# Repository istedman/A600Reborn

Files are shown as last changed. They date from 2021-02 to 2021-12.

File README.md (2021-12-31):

# A600Reborn

Amiga A600 schematics recaptured in KiCad and a new PCB design created from them. 
There is currently one, working, version which replaces the RF modulator with a mini-DIN for S-video.

Schematics and baseline PCB captured by Mick @ EAB. Checked and updated by myself.

Original thread is here: http://eab.abime.net/showthread.php?t=98176

<B>Status as of 23rd February 2021</B><P>
  
The Baseline version is still undergoing testing and is currently not fully functioning, this vairant is not published here.
Use the A600_S_Video branch if you want to try the working variant.

The S-Video variant, which was tracked via manual methods, rather than auto-routed, currently works and boots.
<B> Photos of the S-Video variant<B>

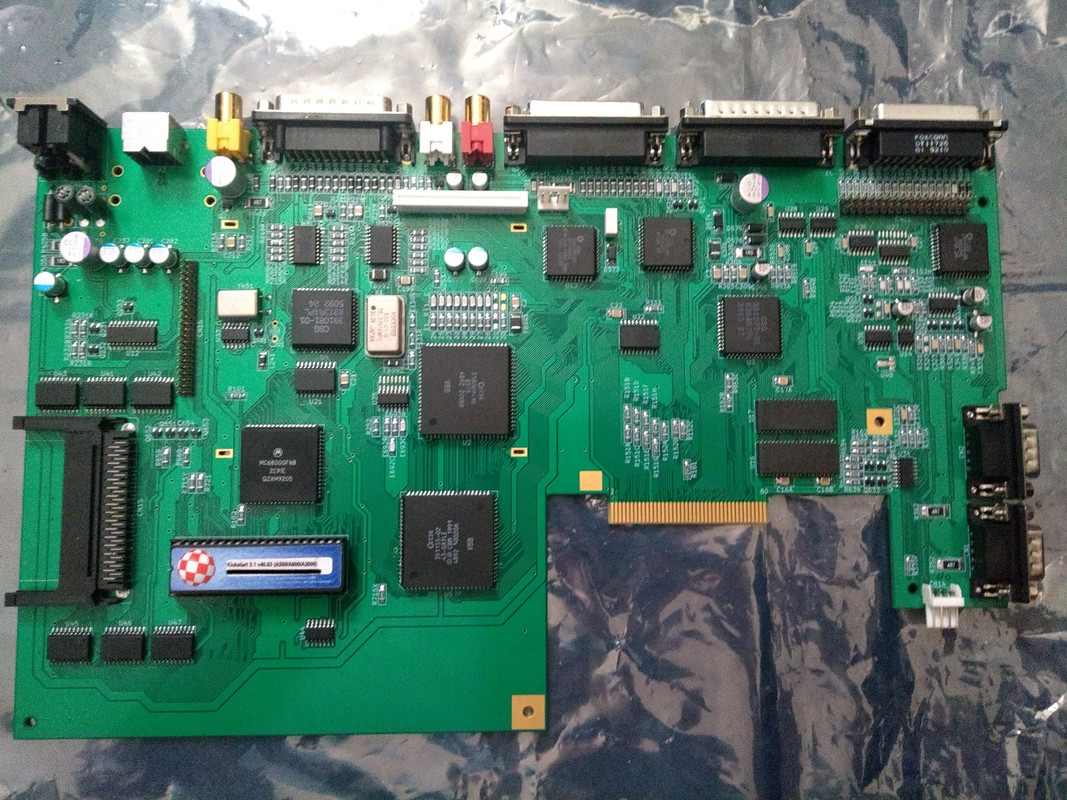
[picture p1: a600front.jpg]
A600 S-Video top

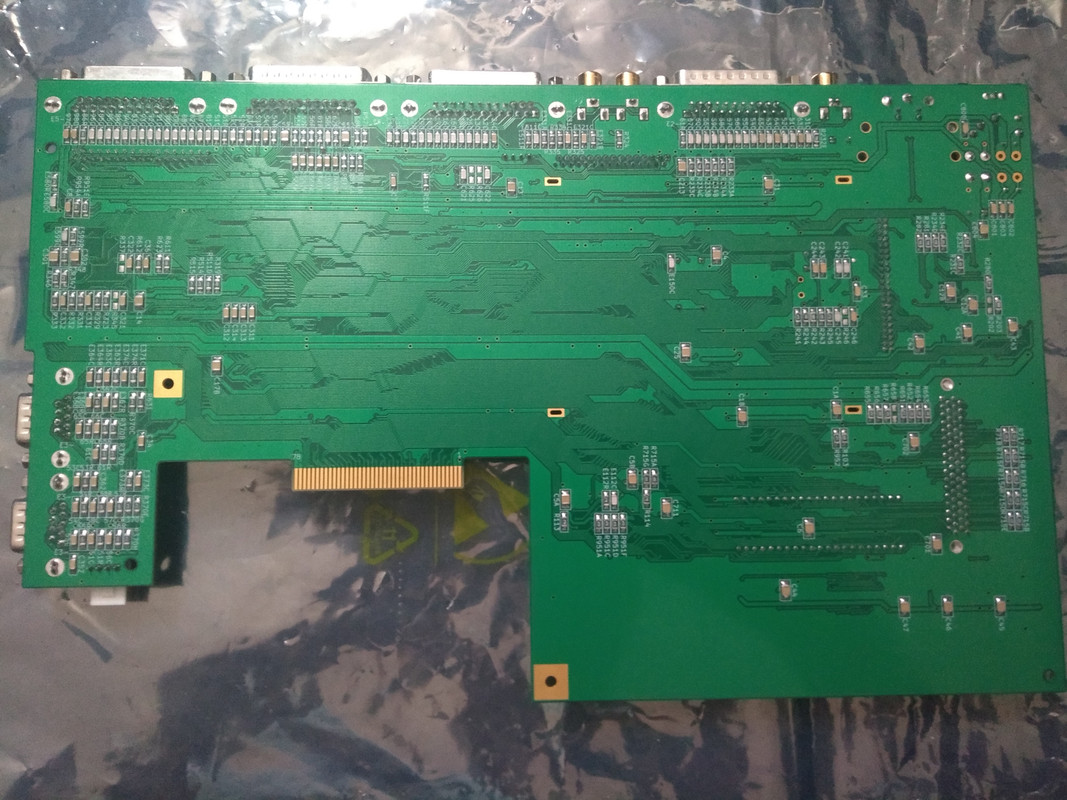
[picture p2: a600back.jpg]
A600 S-Video bottom


Wiki will be updated with debug/test information.

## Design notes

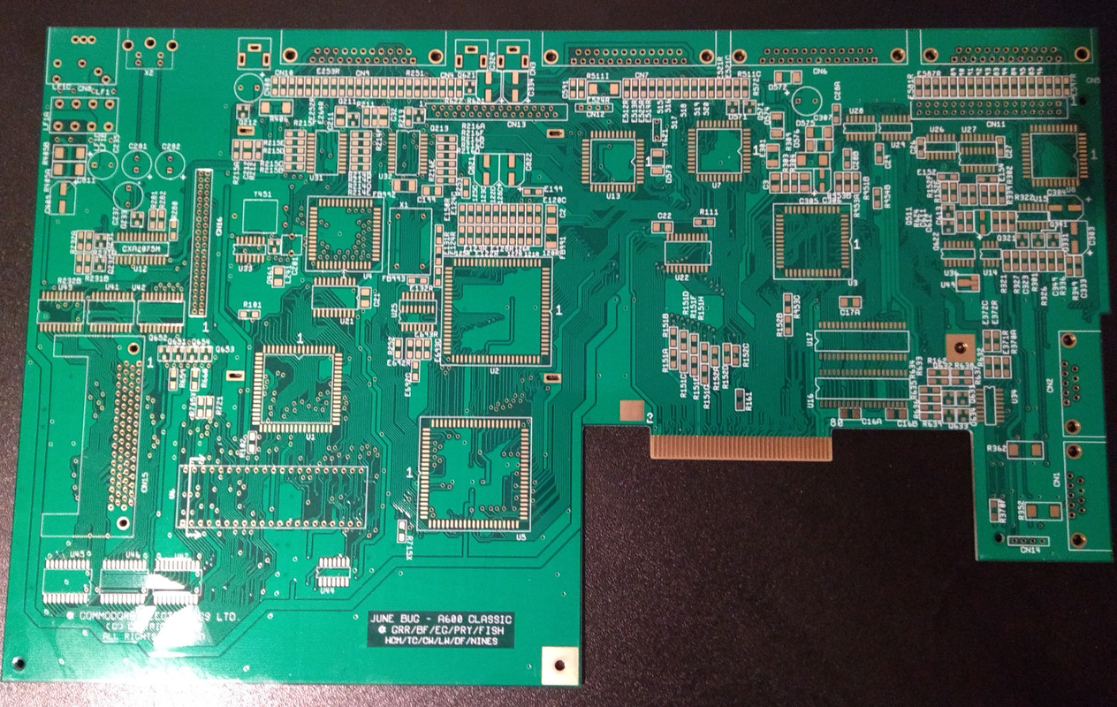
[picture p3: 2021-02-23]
original_pcb_bare.jpg

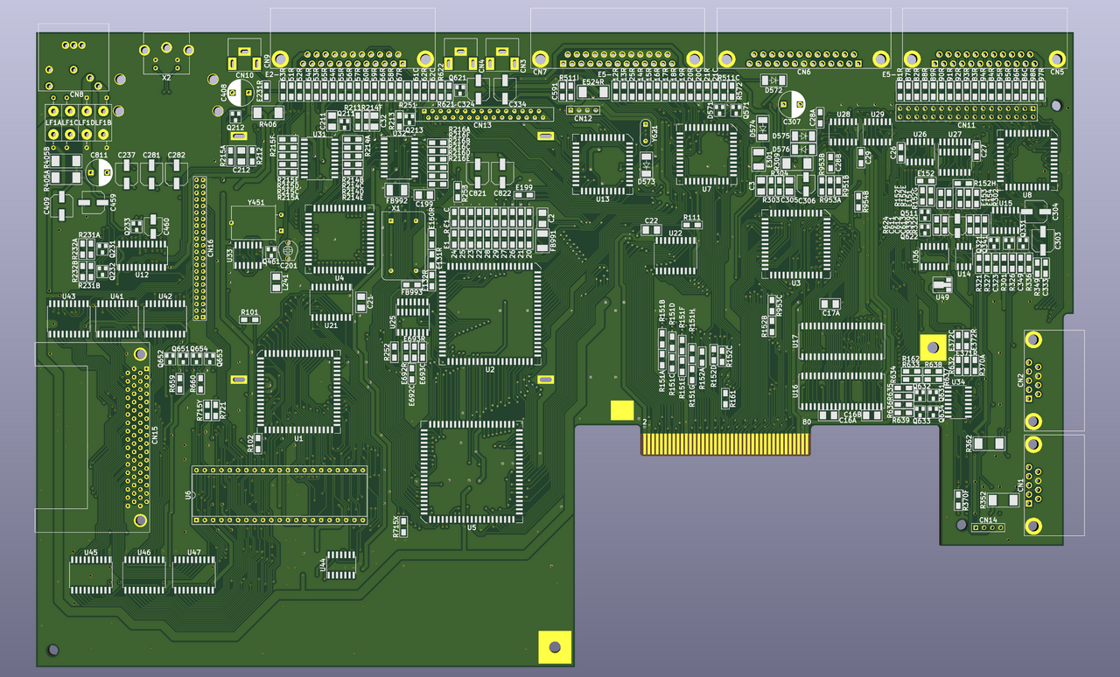
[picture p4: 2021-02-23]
a600pcb-render-front.png

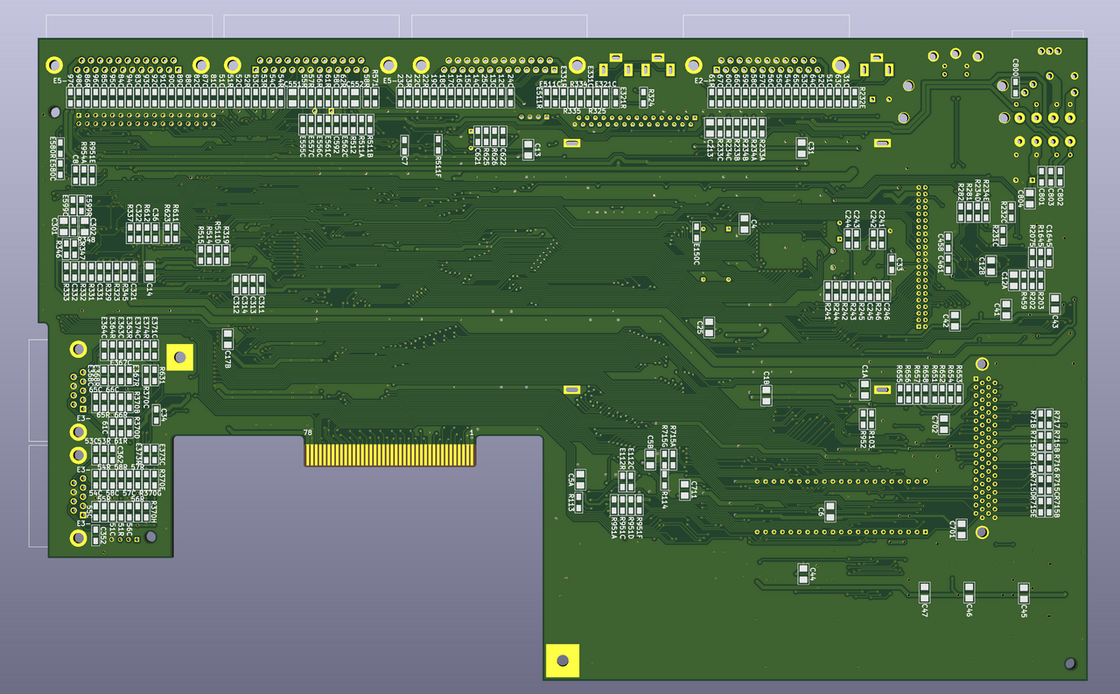
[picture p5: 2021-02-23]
a600pcb-render-back.png

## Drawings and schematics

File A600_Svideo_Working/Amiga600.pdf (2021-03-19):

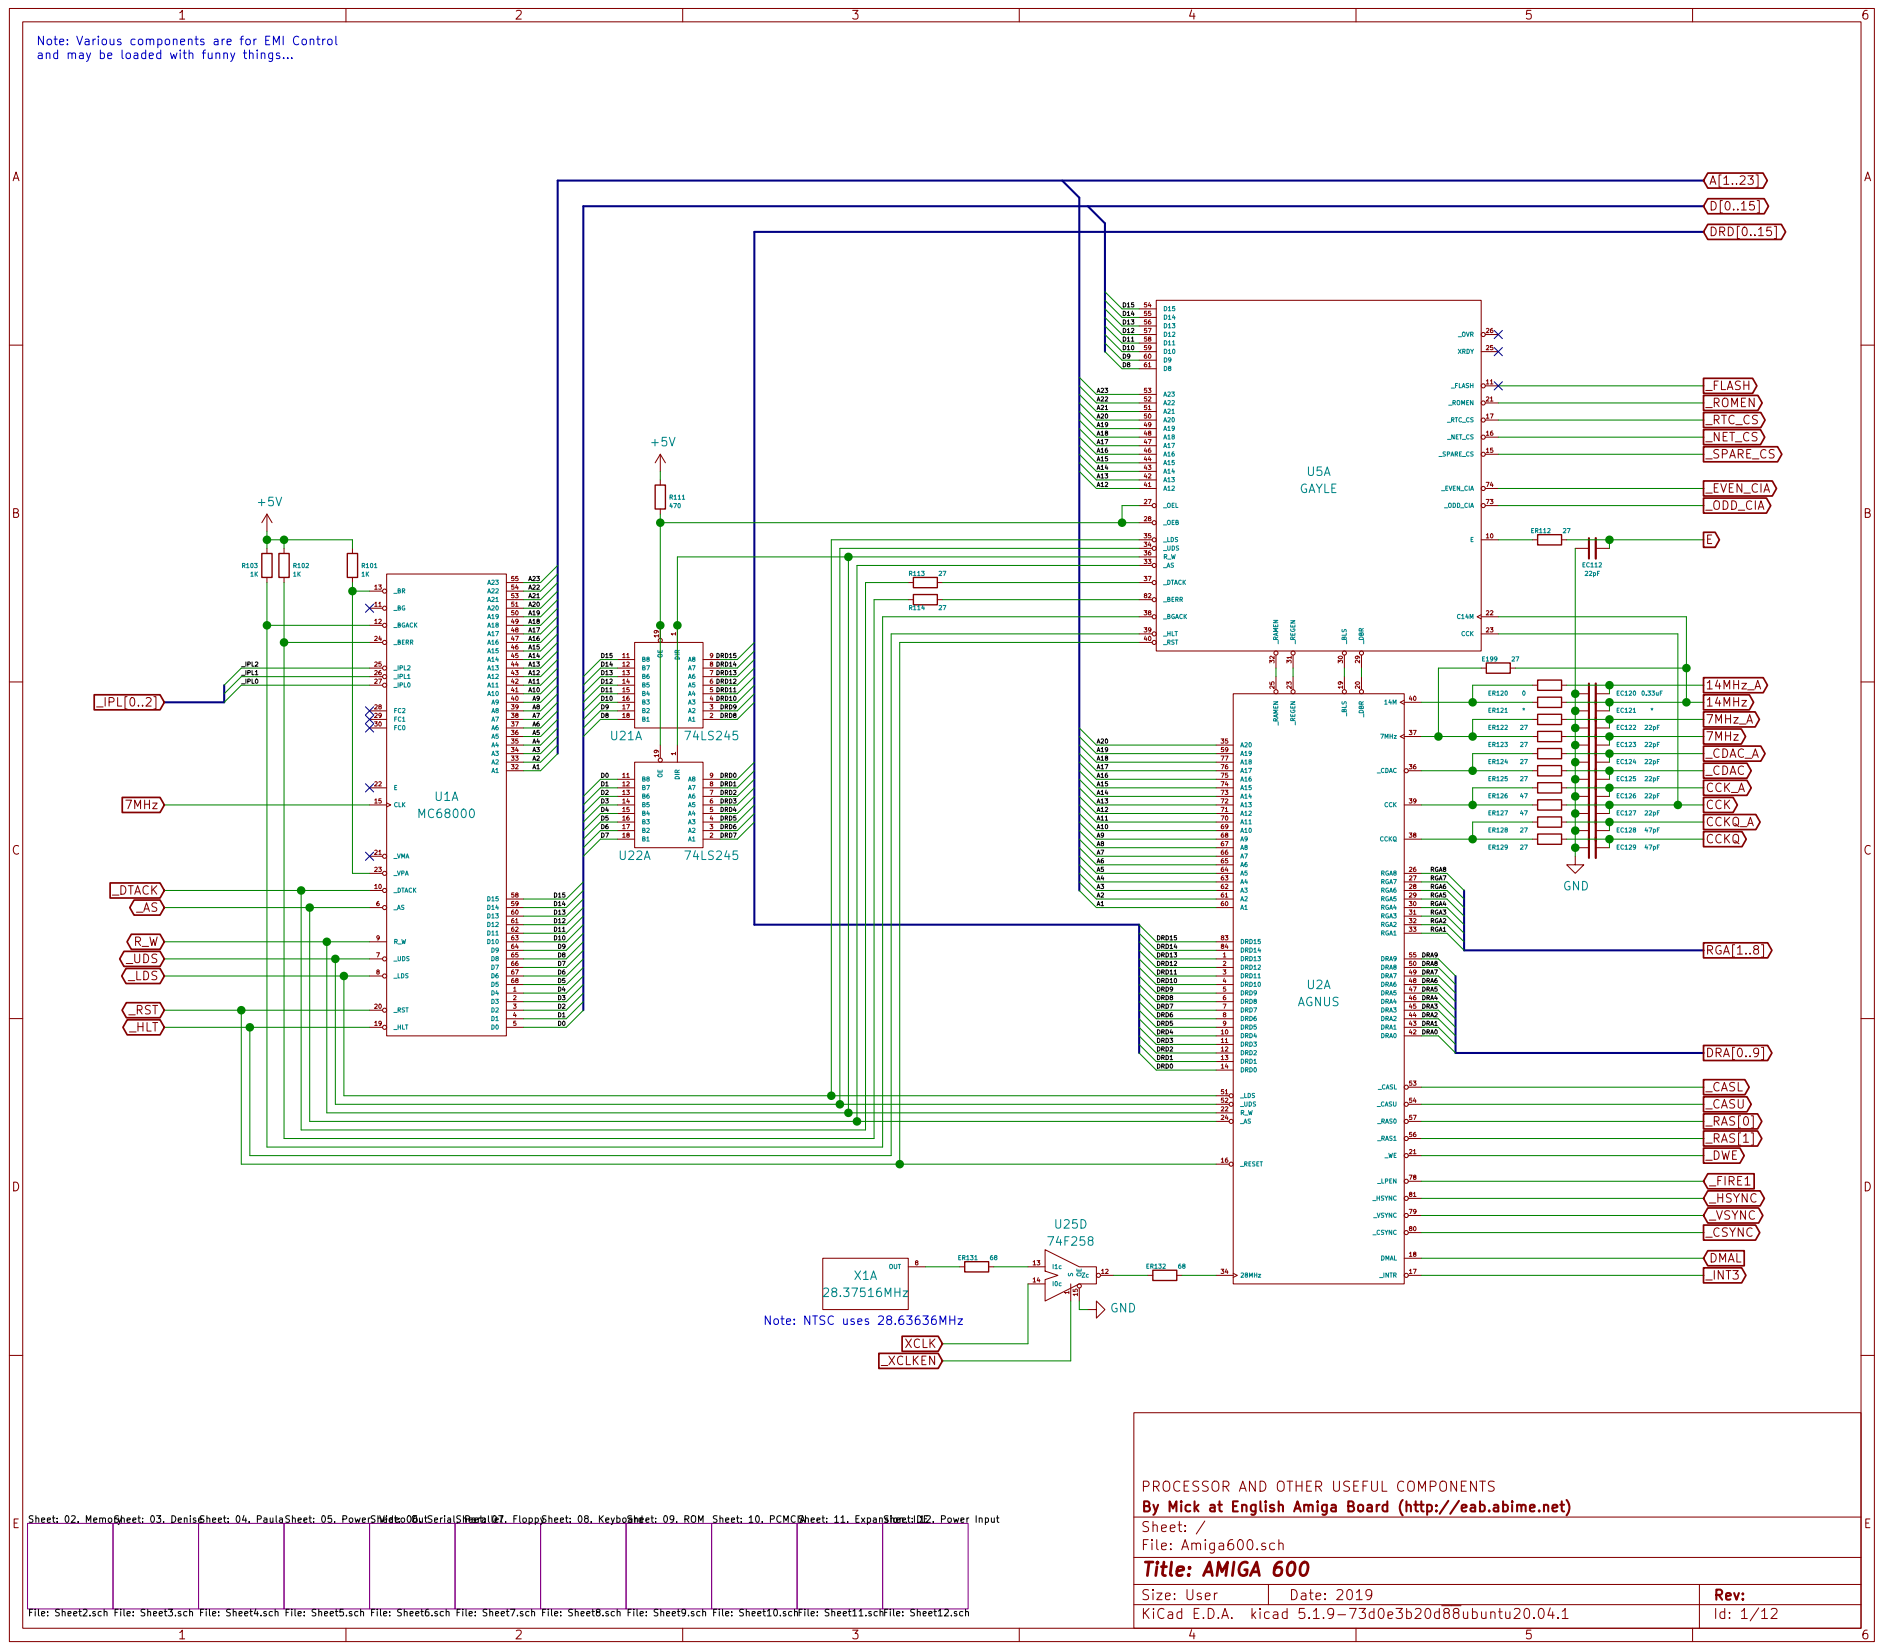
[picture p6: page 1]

Note: Various components are for EMI Control
and may be loaded with funny things...

File: Amiga600.sch Sheet: / By Mick at English Amiga Board (http://eab.abime.net) PROCESSOR AND OTHER USEFUL COMPONENTS

File: Sheet10.sch Sheet: 09. ROM

File: Sheet11.sch Sheet: 10. PCMCIA

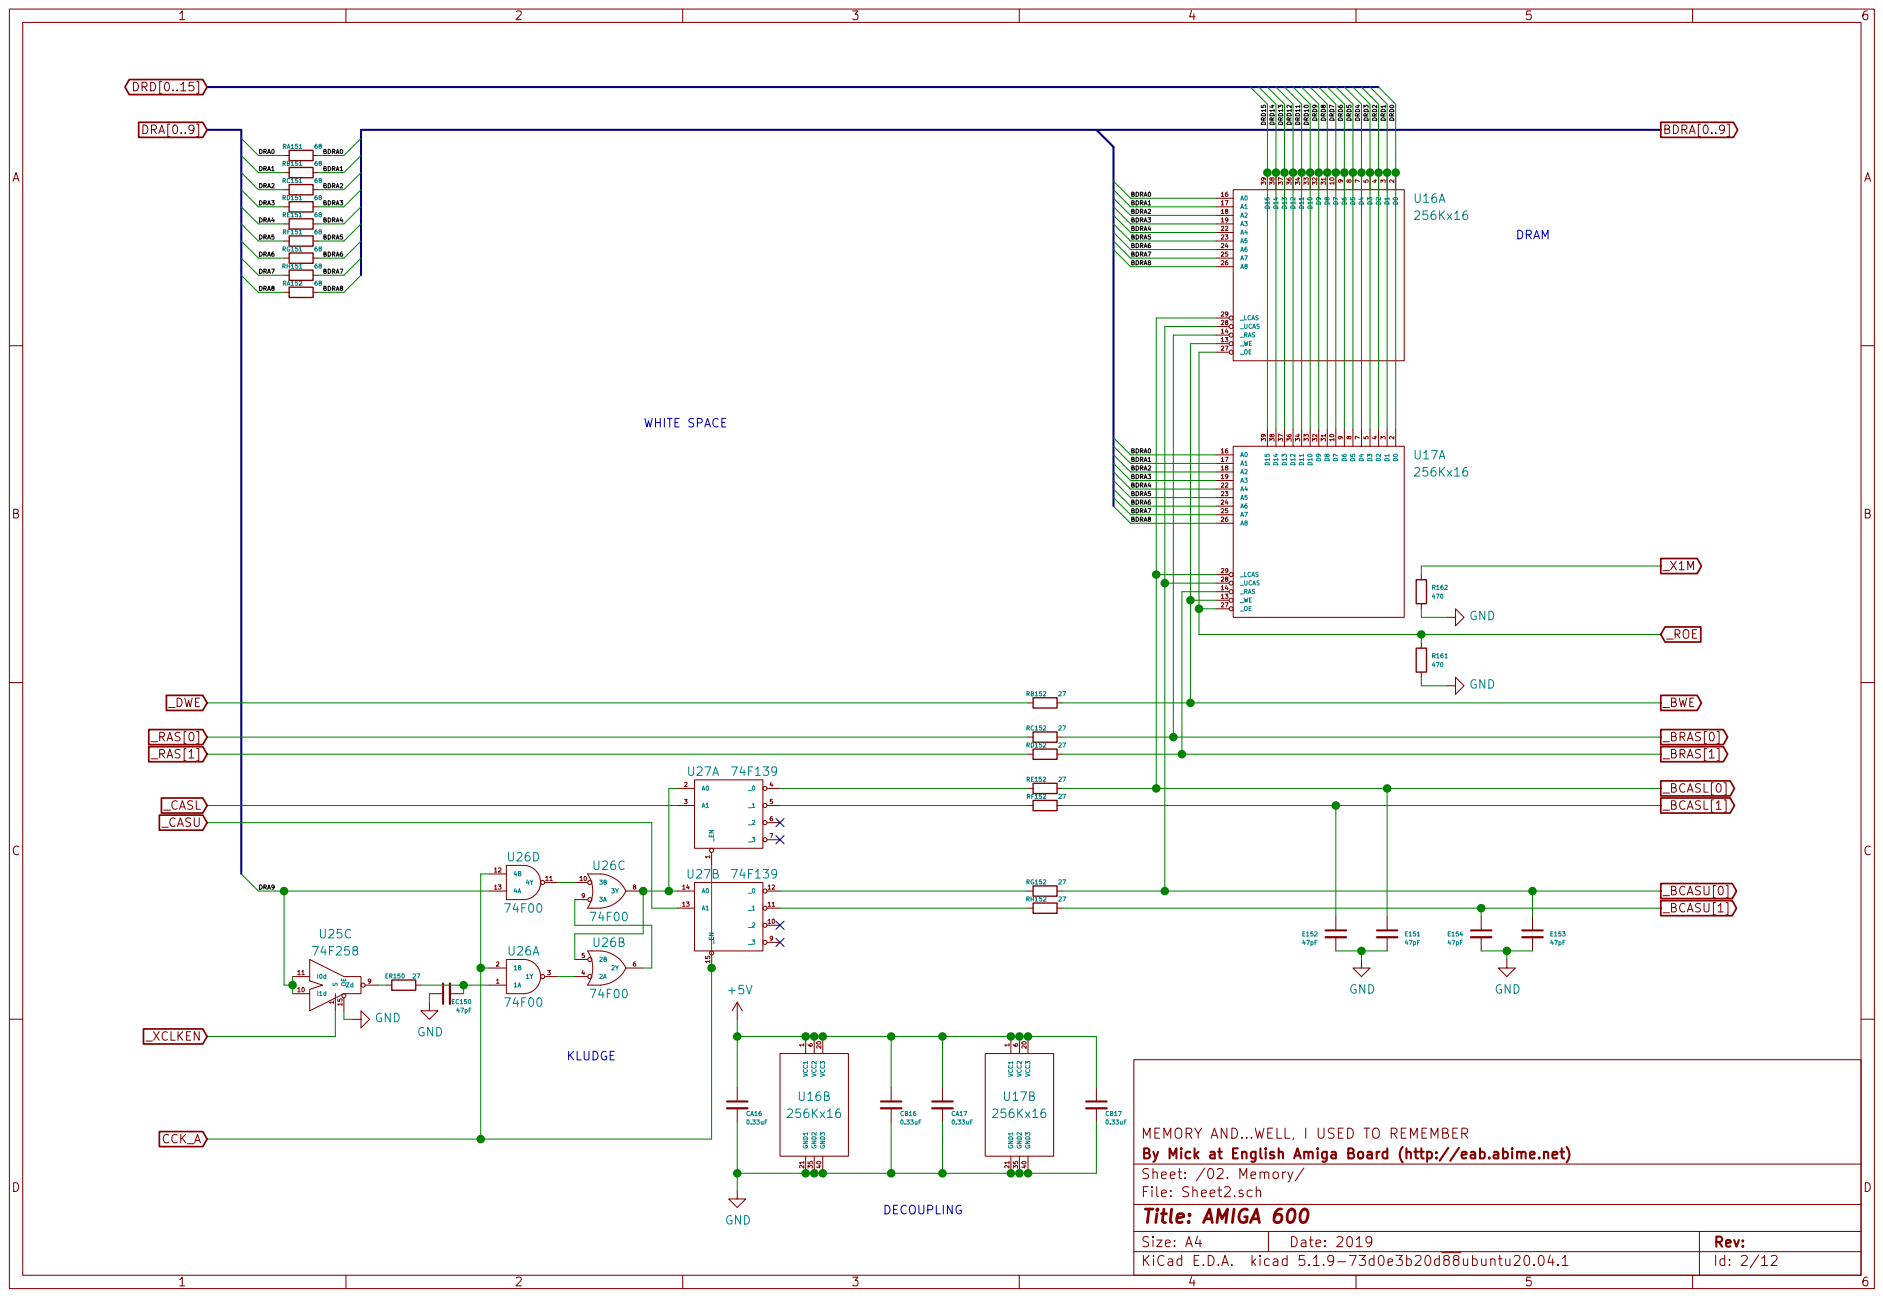
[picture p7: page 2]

MEMORY AND...WELL, I USED TO REMEMBER
By Mick at English Amiga Board (http://eab.abime.net)
File: Sheet2.sch Sheet: /02. Memory/
Id: 2/12 Title: AMIGA 600

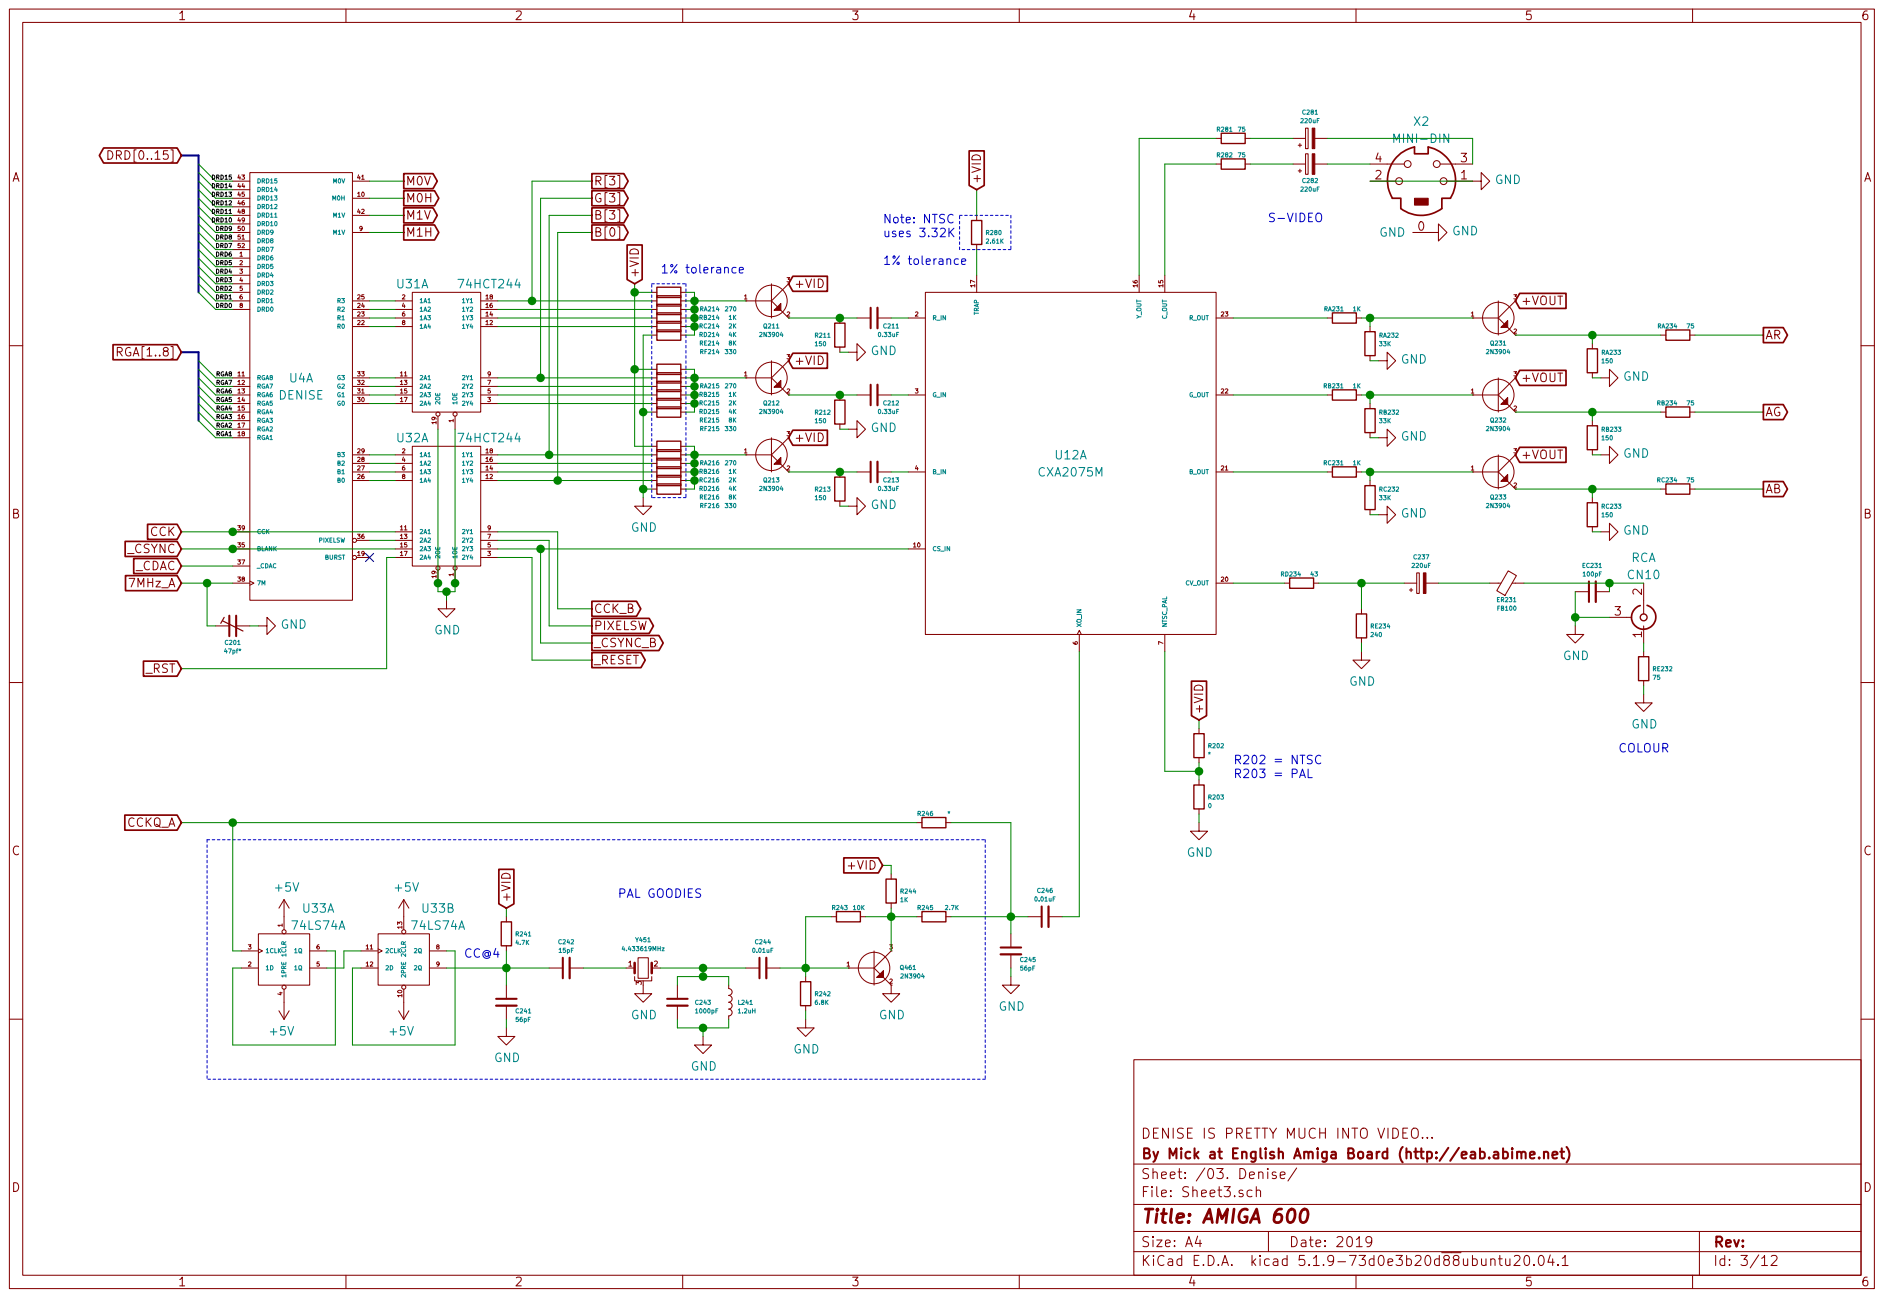
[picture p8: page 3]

1A1 2 | | 1Y1 1Y2 1Y3 1Y4 | 18 2OE 19
1A2 4 | | | 16
1A3 6 | | | 14
1A4 8 | | | 12

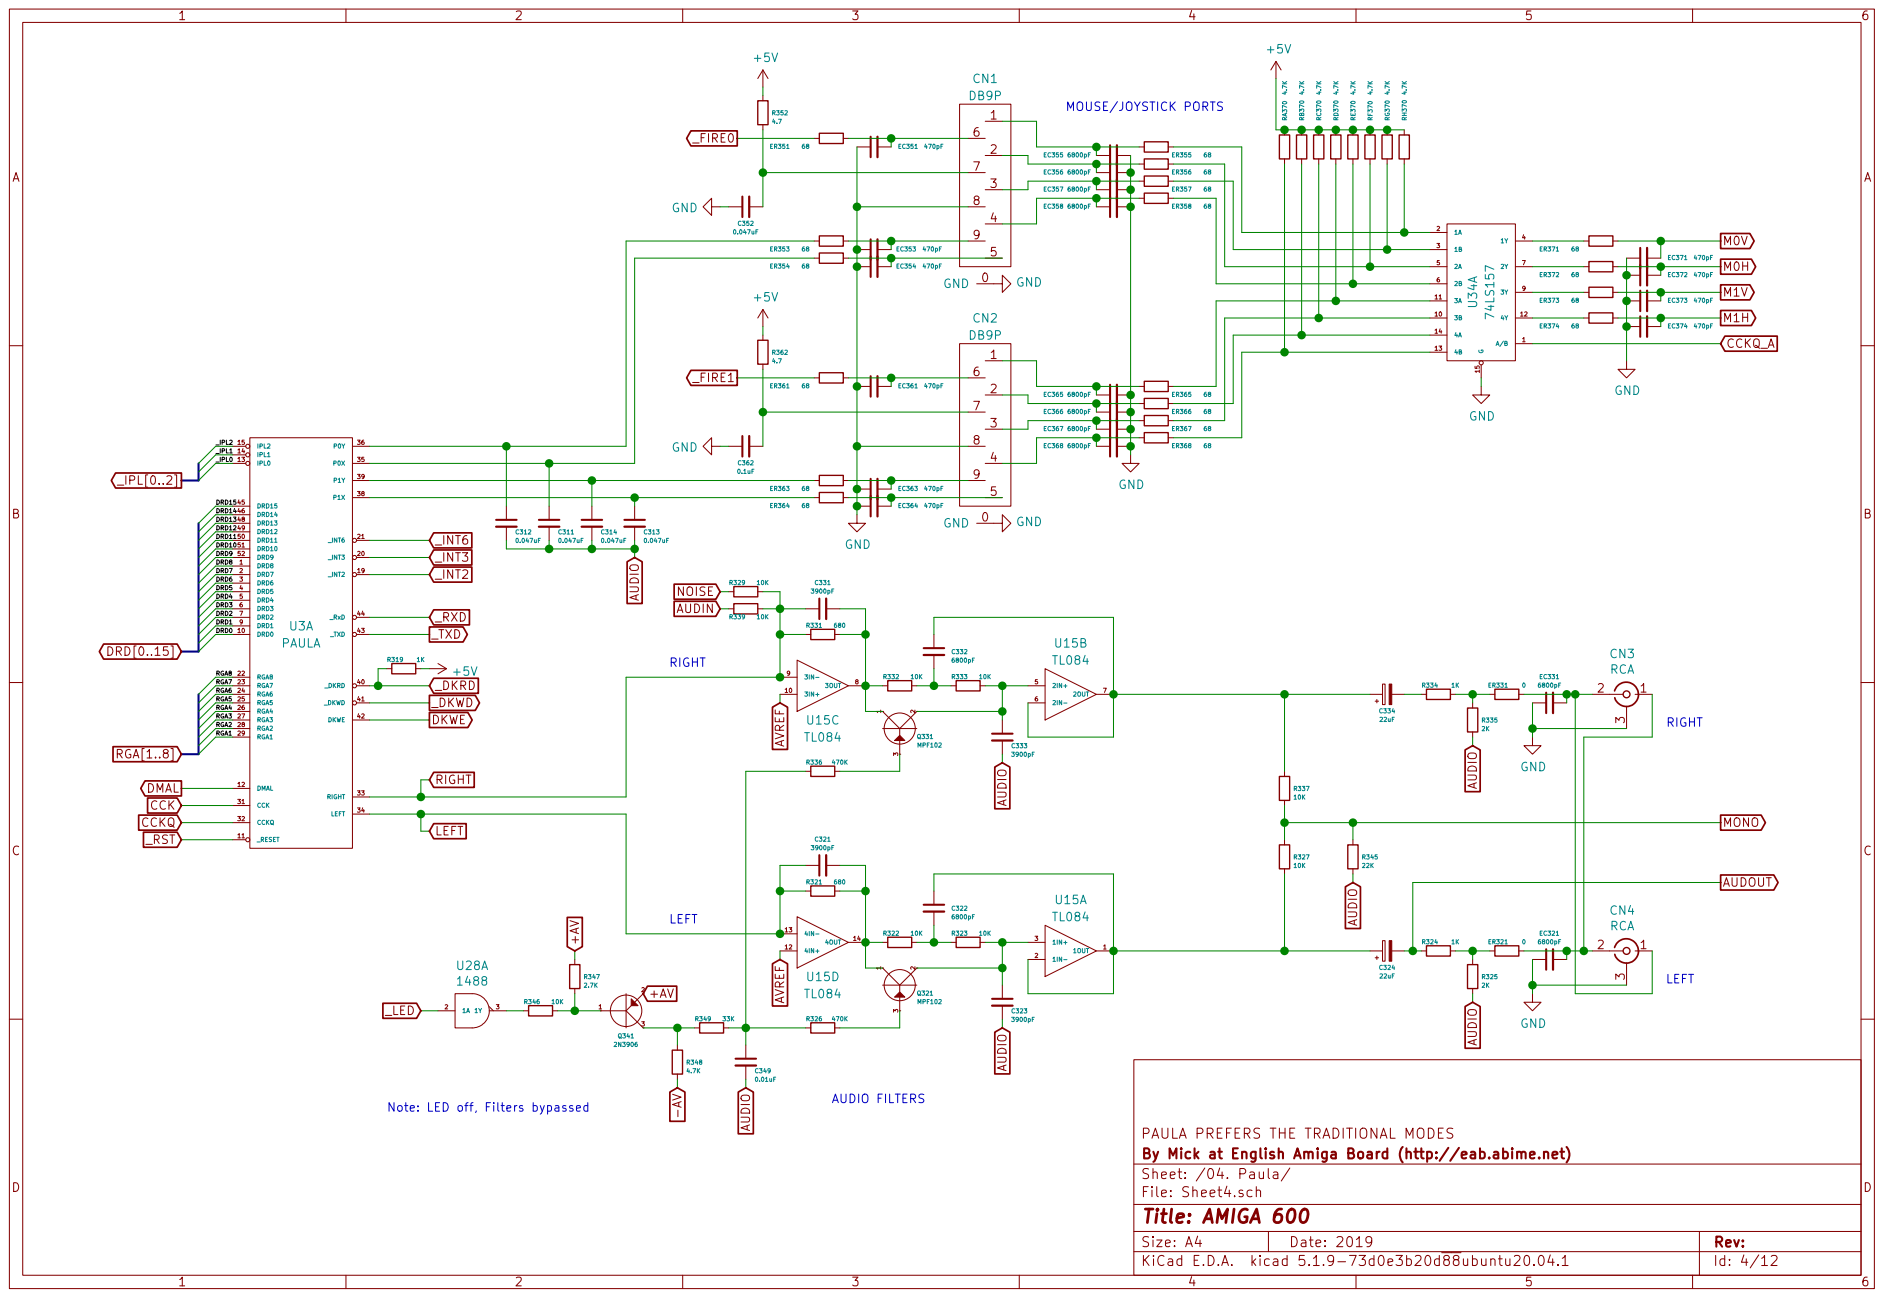
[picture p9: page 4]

LEFT RIGHT Note: LED off, Filters bypassed

File: Sheet4.sch Sheet: /04. Paula/ By Mick at English Amiga Board (http://eab.abime.net) PAULA PREFERS THE TRADITIONAL MODES

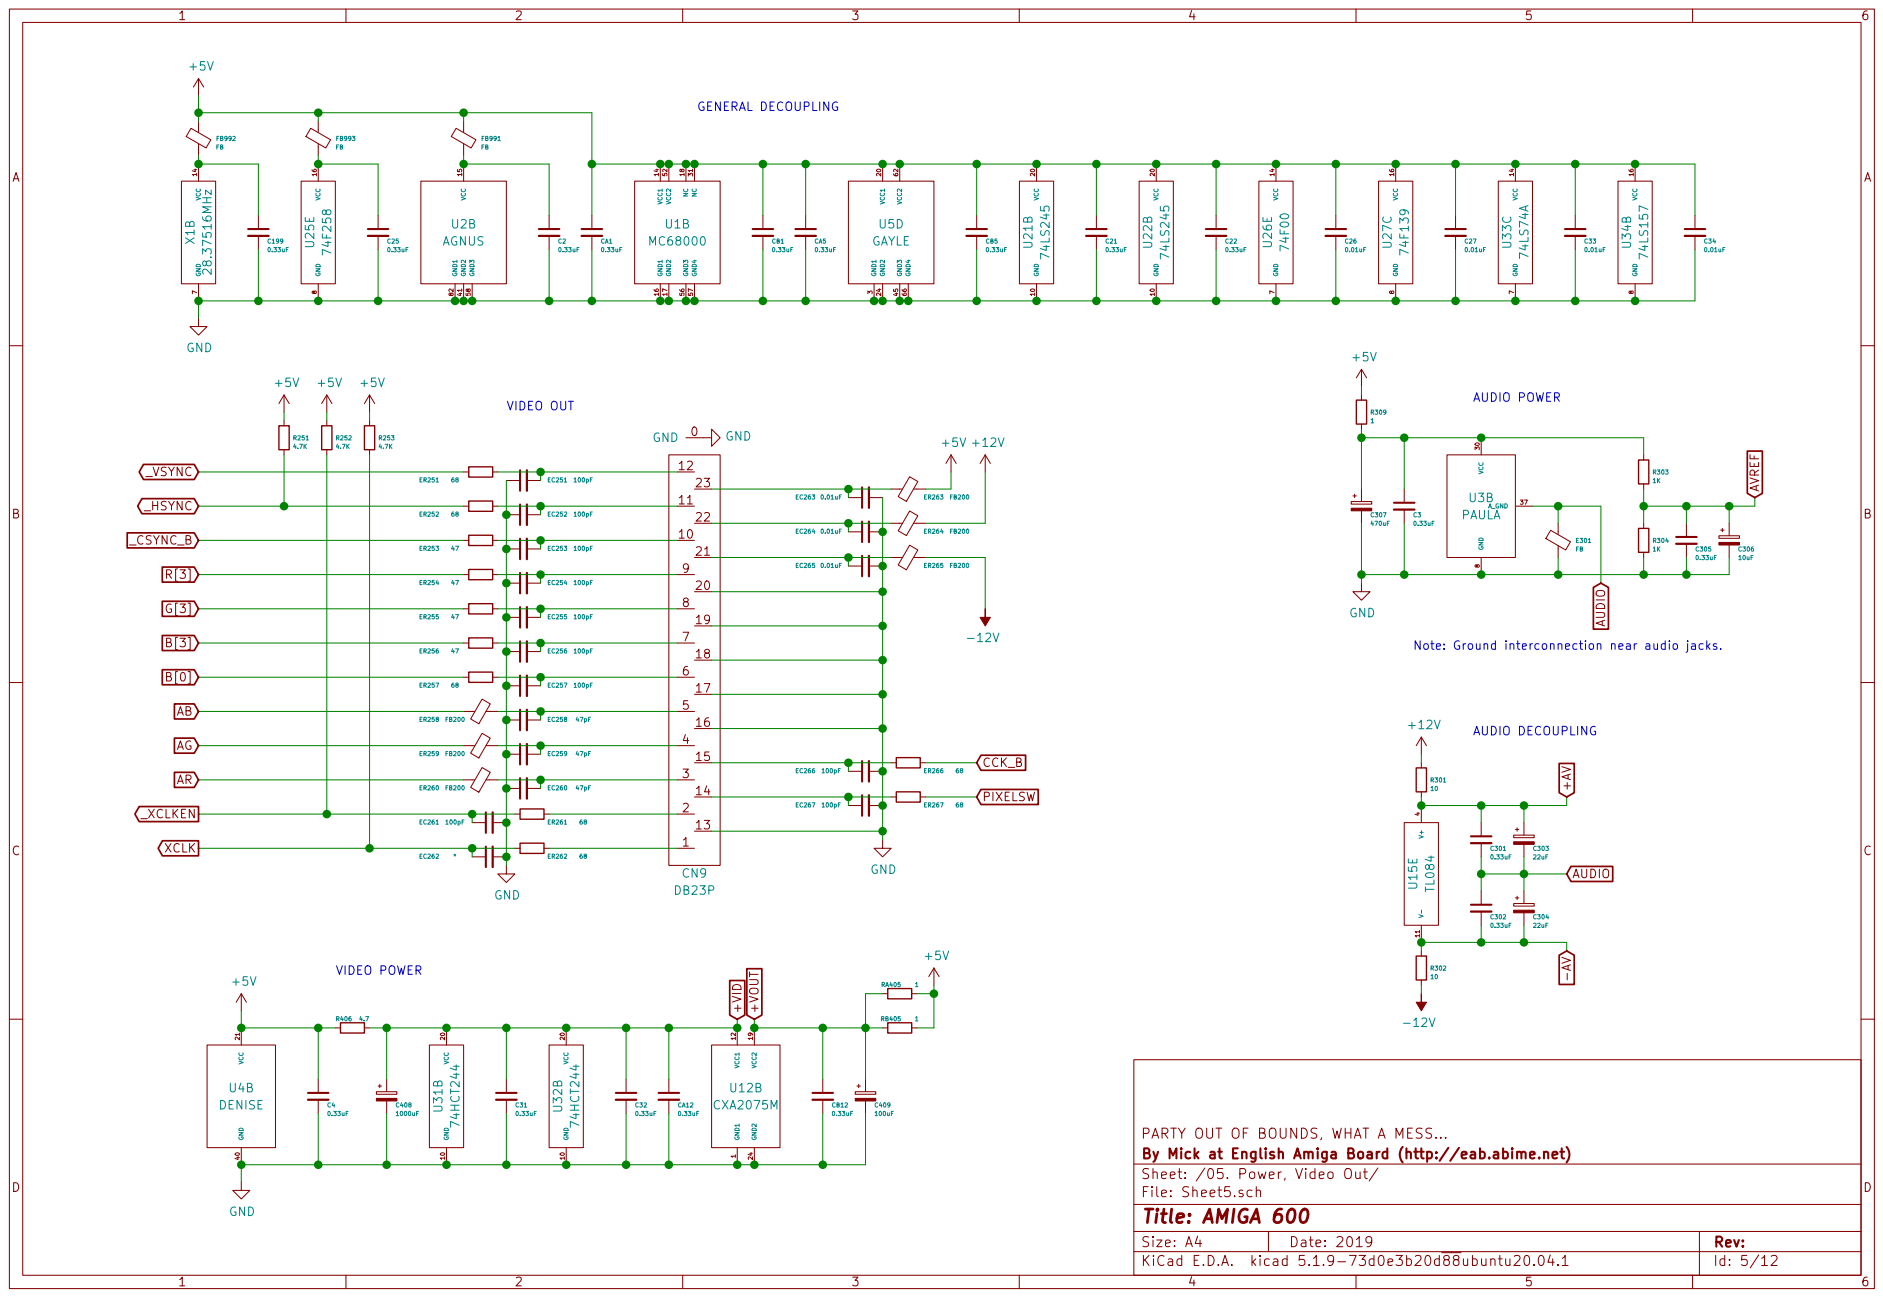
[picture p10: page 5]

3 GND3 45 VCC2 62 GND4 66 U5D GAYLE GND 10 VCC 20 U21B 74LS245 GND 10 VCC 20 U22B 74LS245 VCC 14 GND

Note: Ground interconnection near audio jacks. AUDIO POWER

By Mick at English Amiga Board (http://eab.abime.net)
File: Sheet5.sch Sheet: /05. Power, Video Out/
Id: 5/12 Title: AMIGA 600

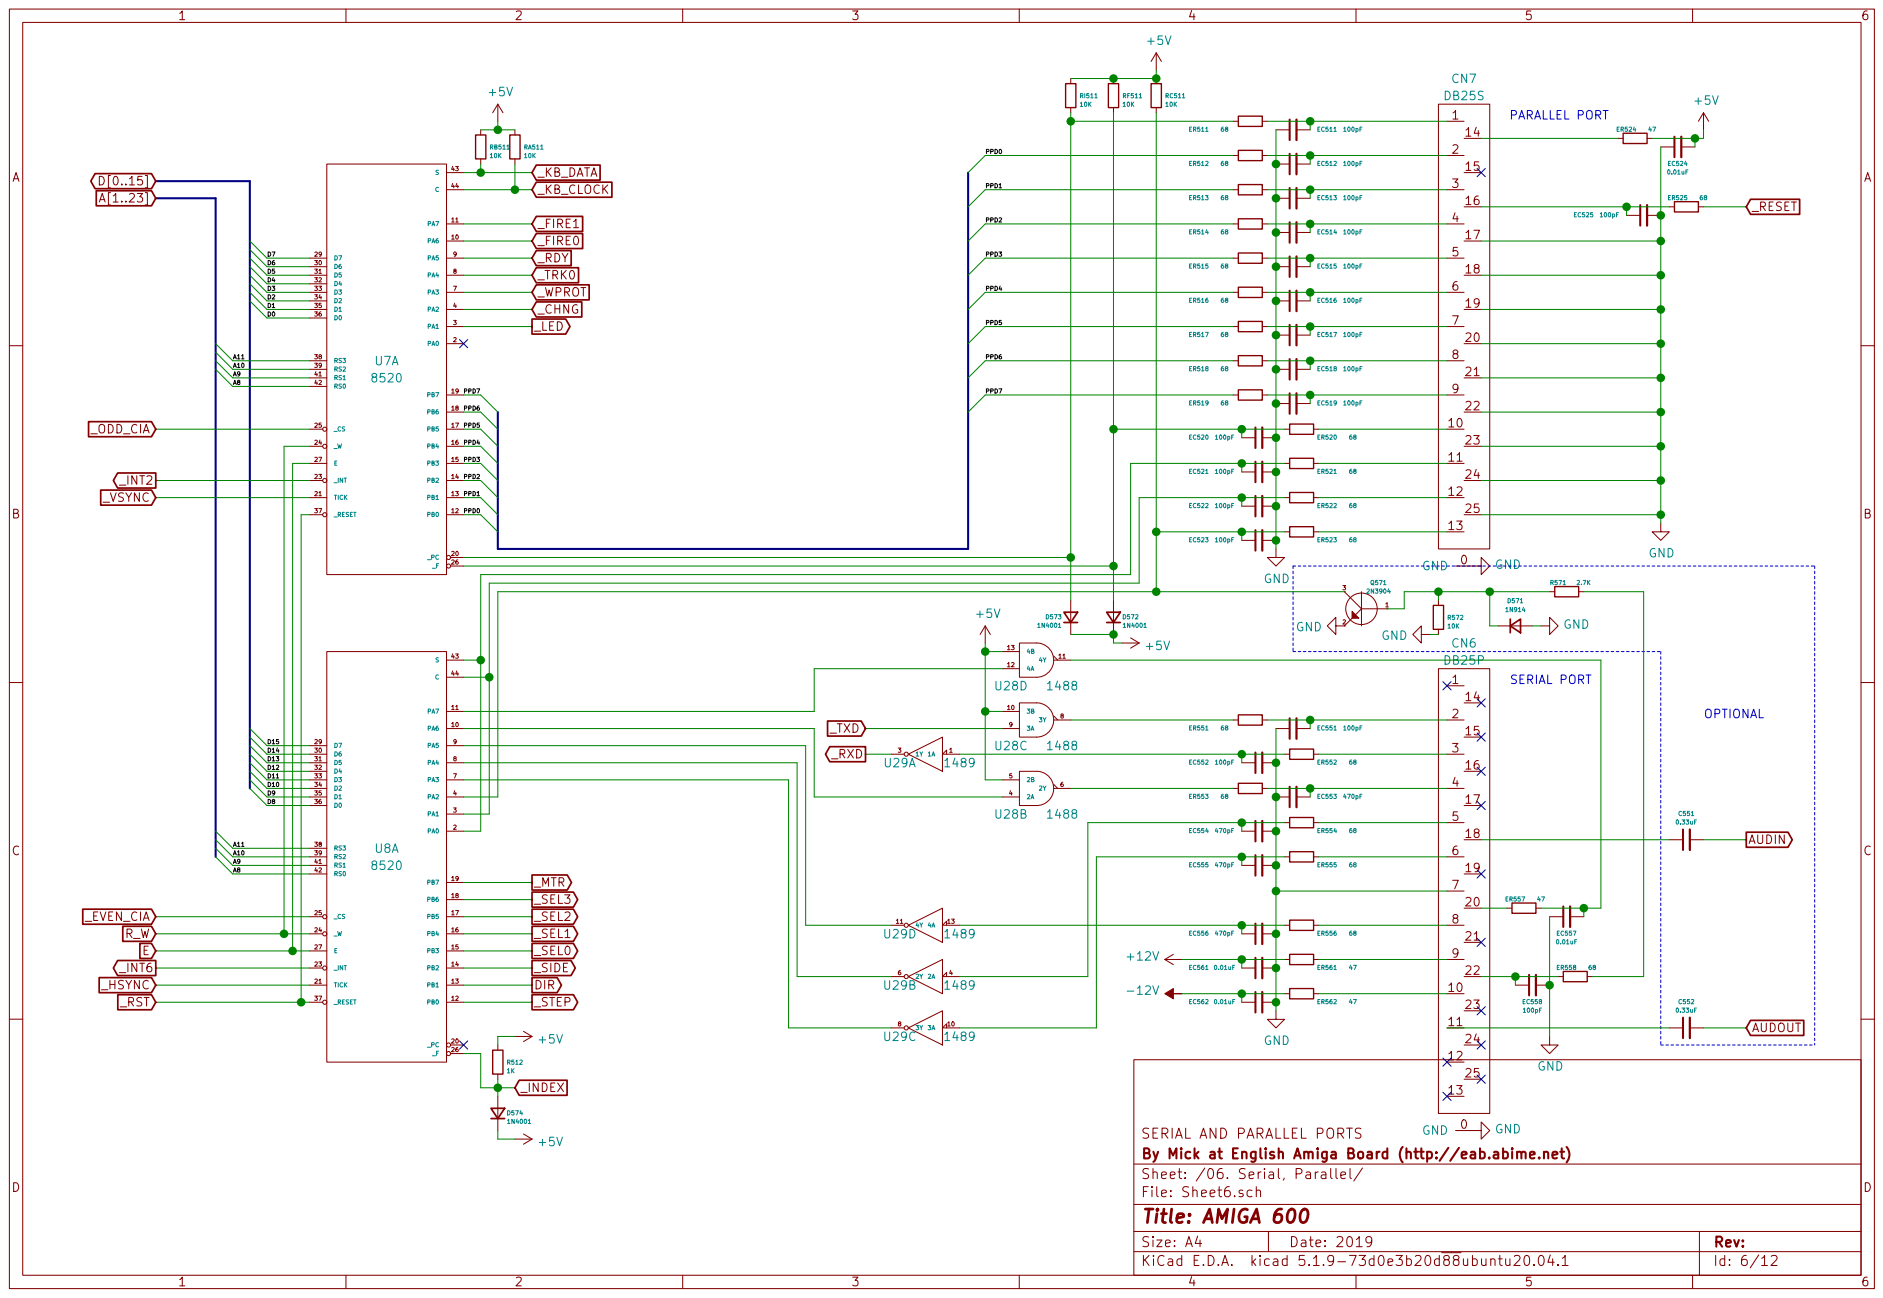
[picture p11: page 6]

By Mick at English Amiga Board (http://eab.abime.net) SERIAL AND PARALLEL PORTS

File: Sheet6.sch Sheet: /06. Serial, Parallel/
Id: 6/12 Title: AMIGA 600

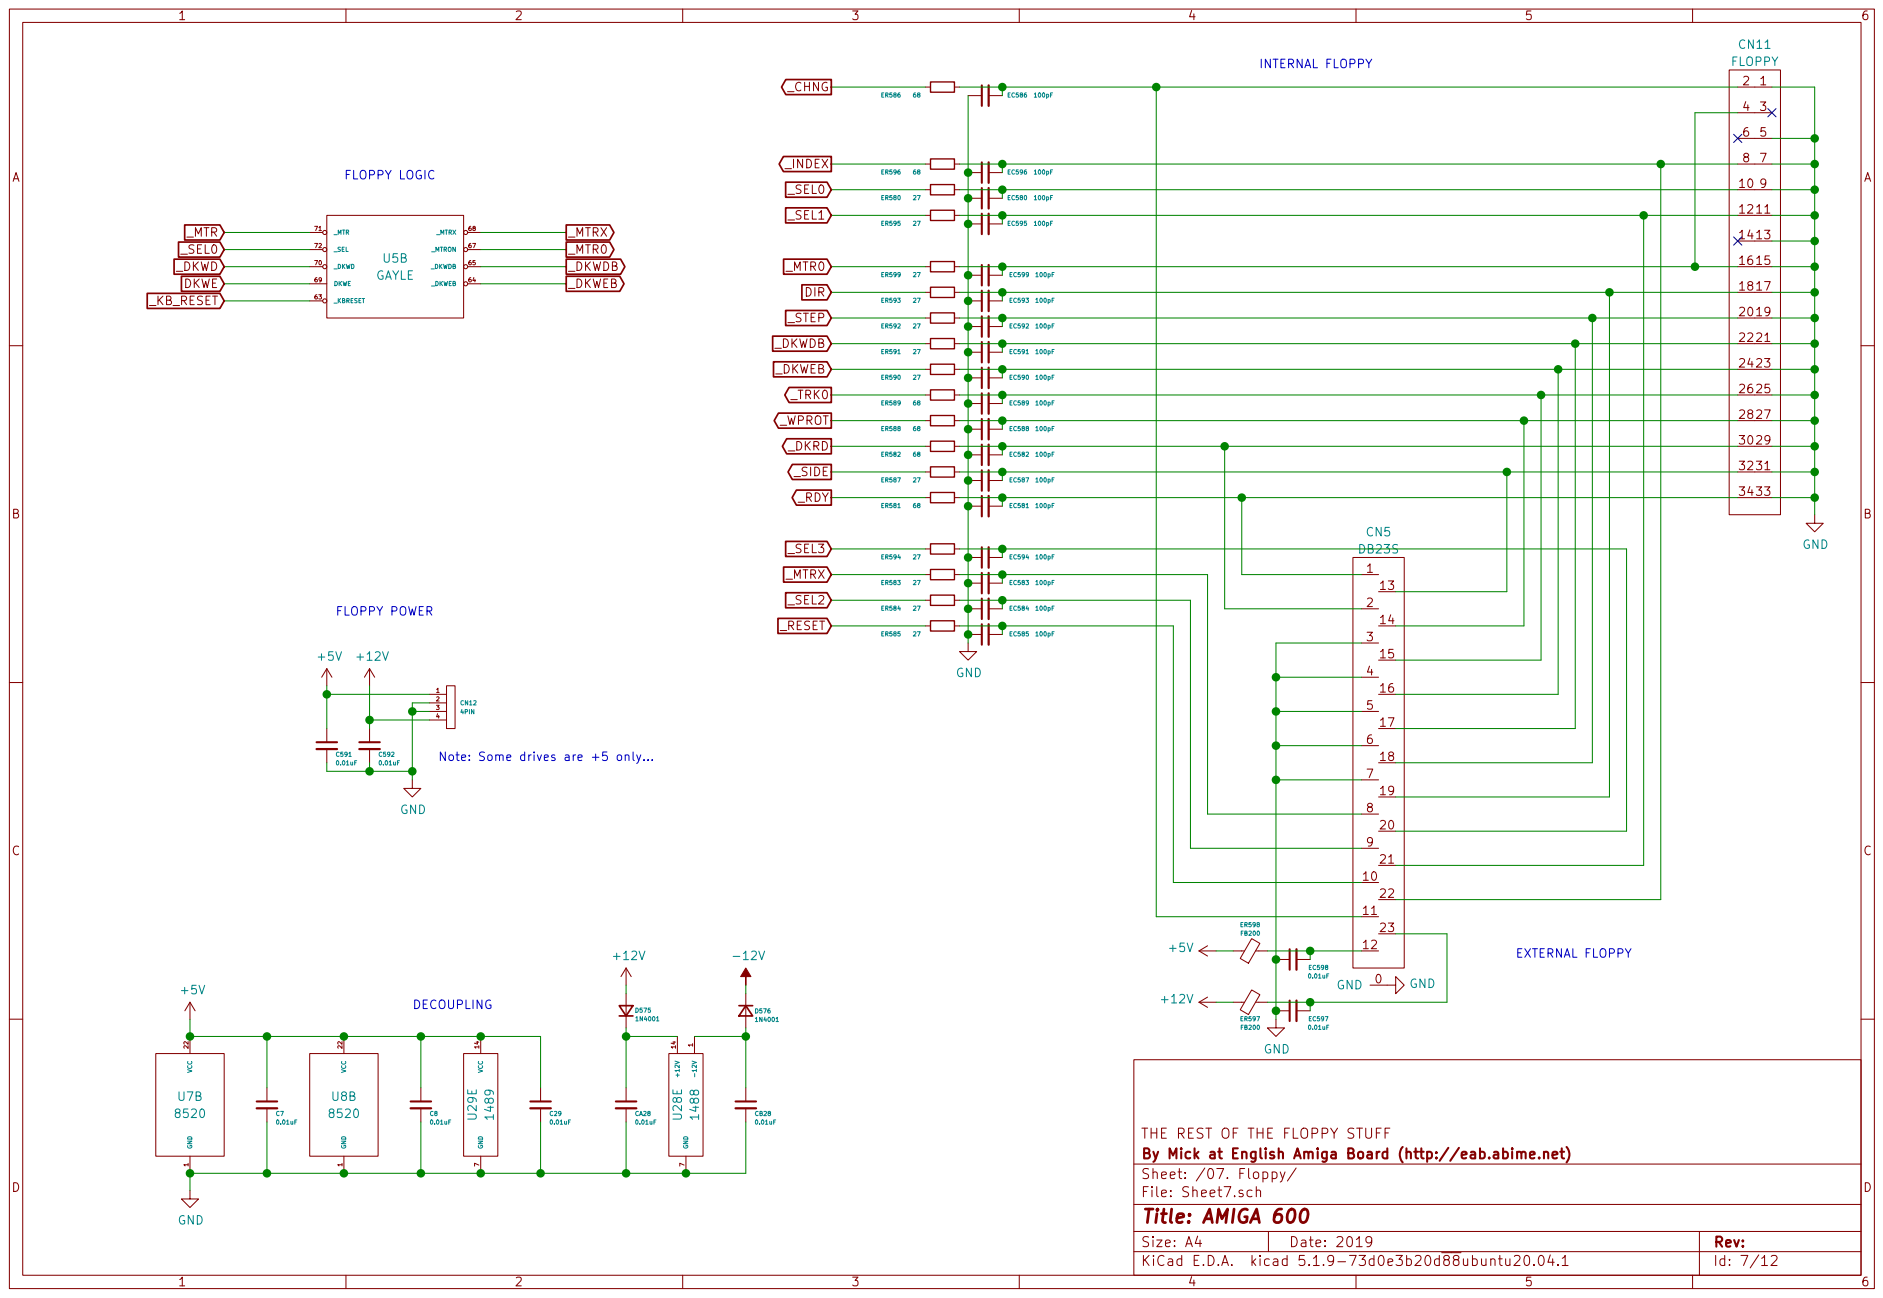
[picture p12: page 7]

34 33 46 5 8 79 CN11 FLOPPY 12 11
19 2

18 17
20
22 21
24 23
26 25
28 27
30 29
32 31

Note: Some drives are +5 only...

By Mick at English Amiga Board (http://eab.abime.net) THE REST OF THE FLOPPY STUFF

File: Sheet7.sch Sheet: /07. Floppy/
Id: 7/12 Title: AMIGA 600

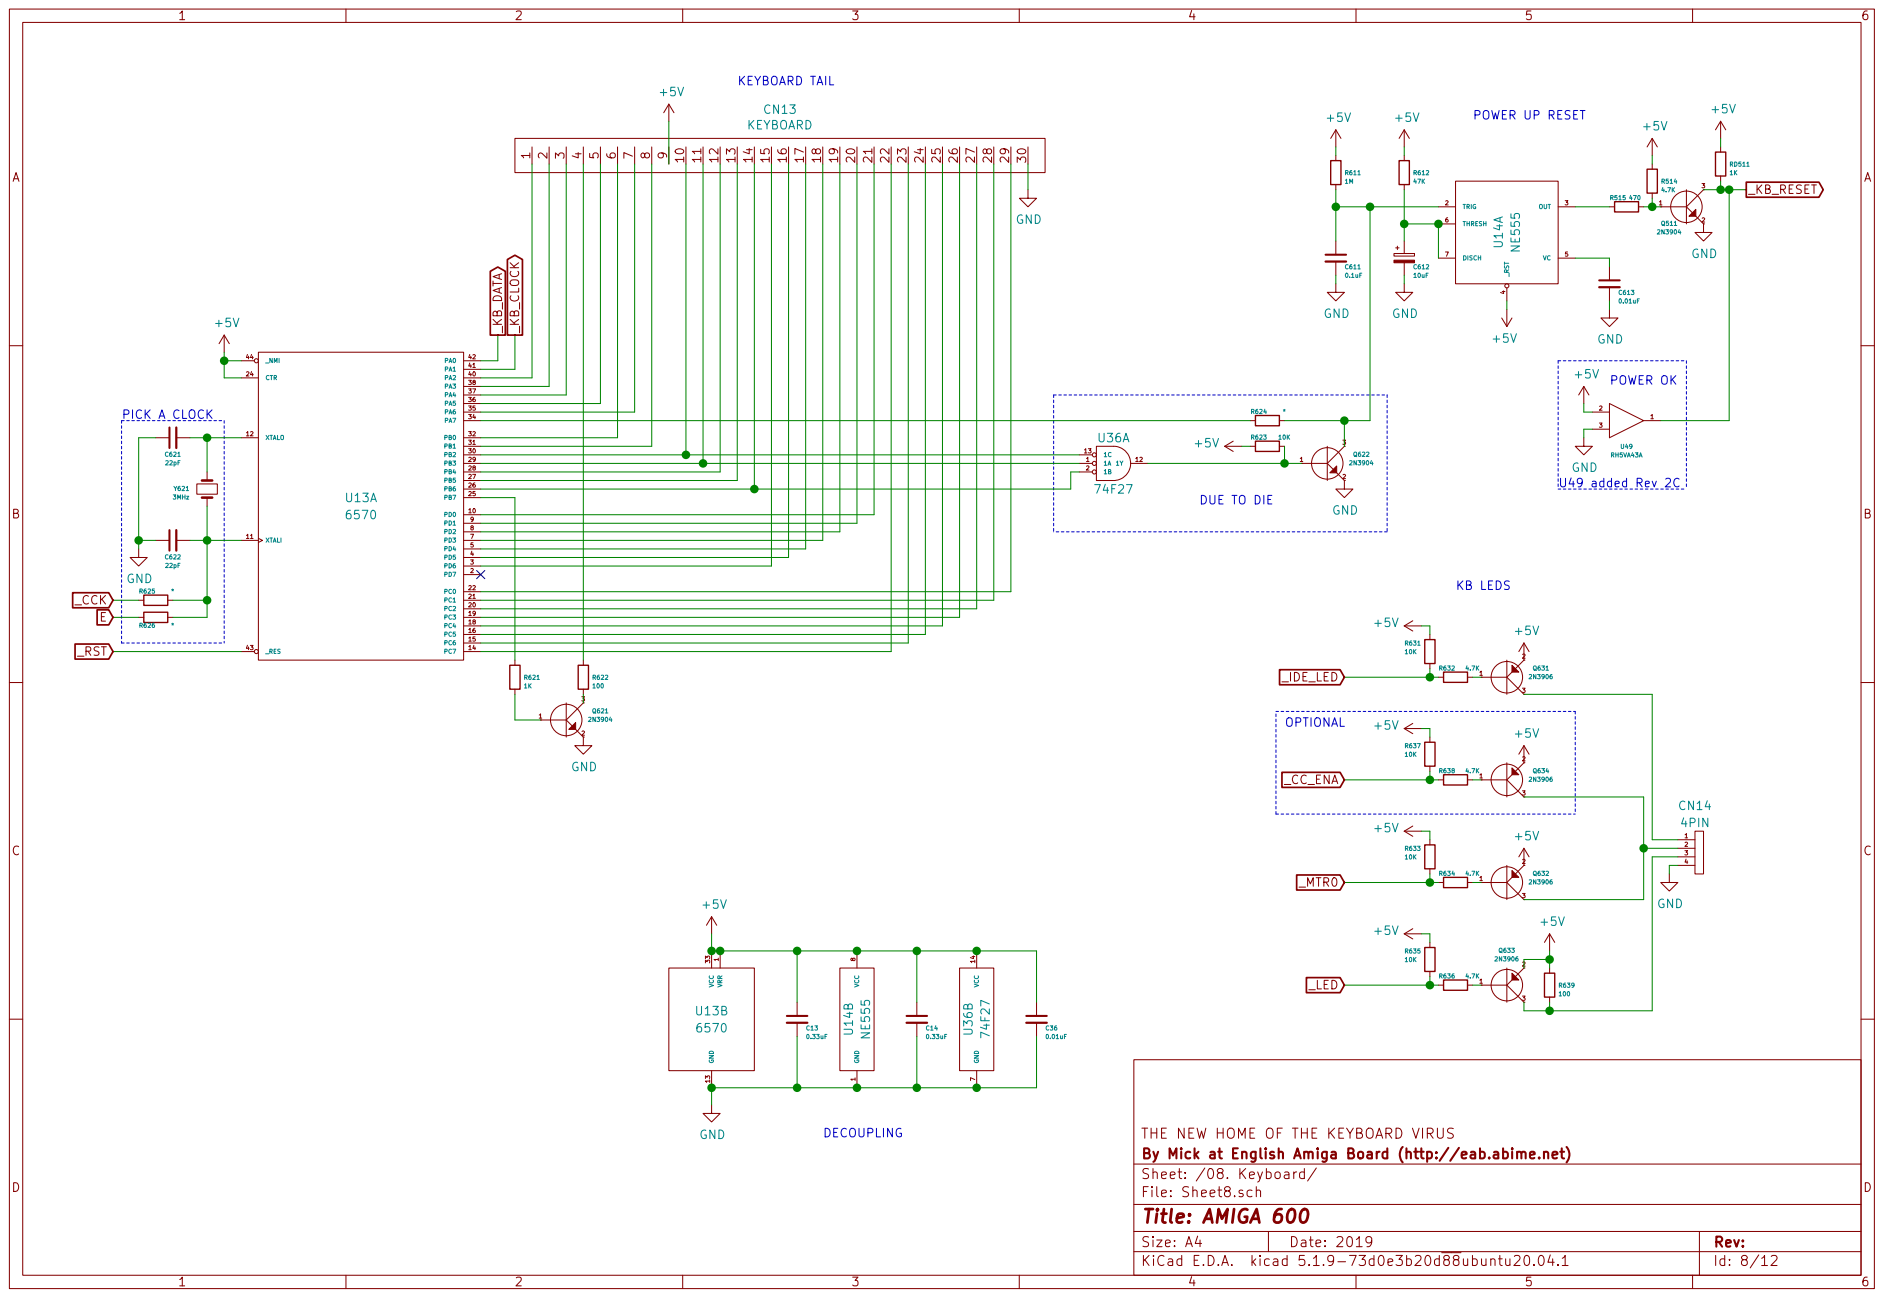
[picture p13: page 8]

POWER UP RESET KEYBOARD TAIL

4 VC 5 THRESH 6 DISCH 7 U14A NE555 GND

POWER OK U49 added Rev 2C OPTIONAL DUE TO DIE

By Mick at English Amiga Board (http://eab.abime.net) THE NEW HOME OF THE KEYBOARD VIRUS

File: Sheet8.sch Sheet: /08. Keyboard/
Id: 8/12 Title: AMIGA 600

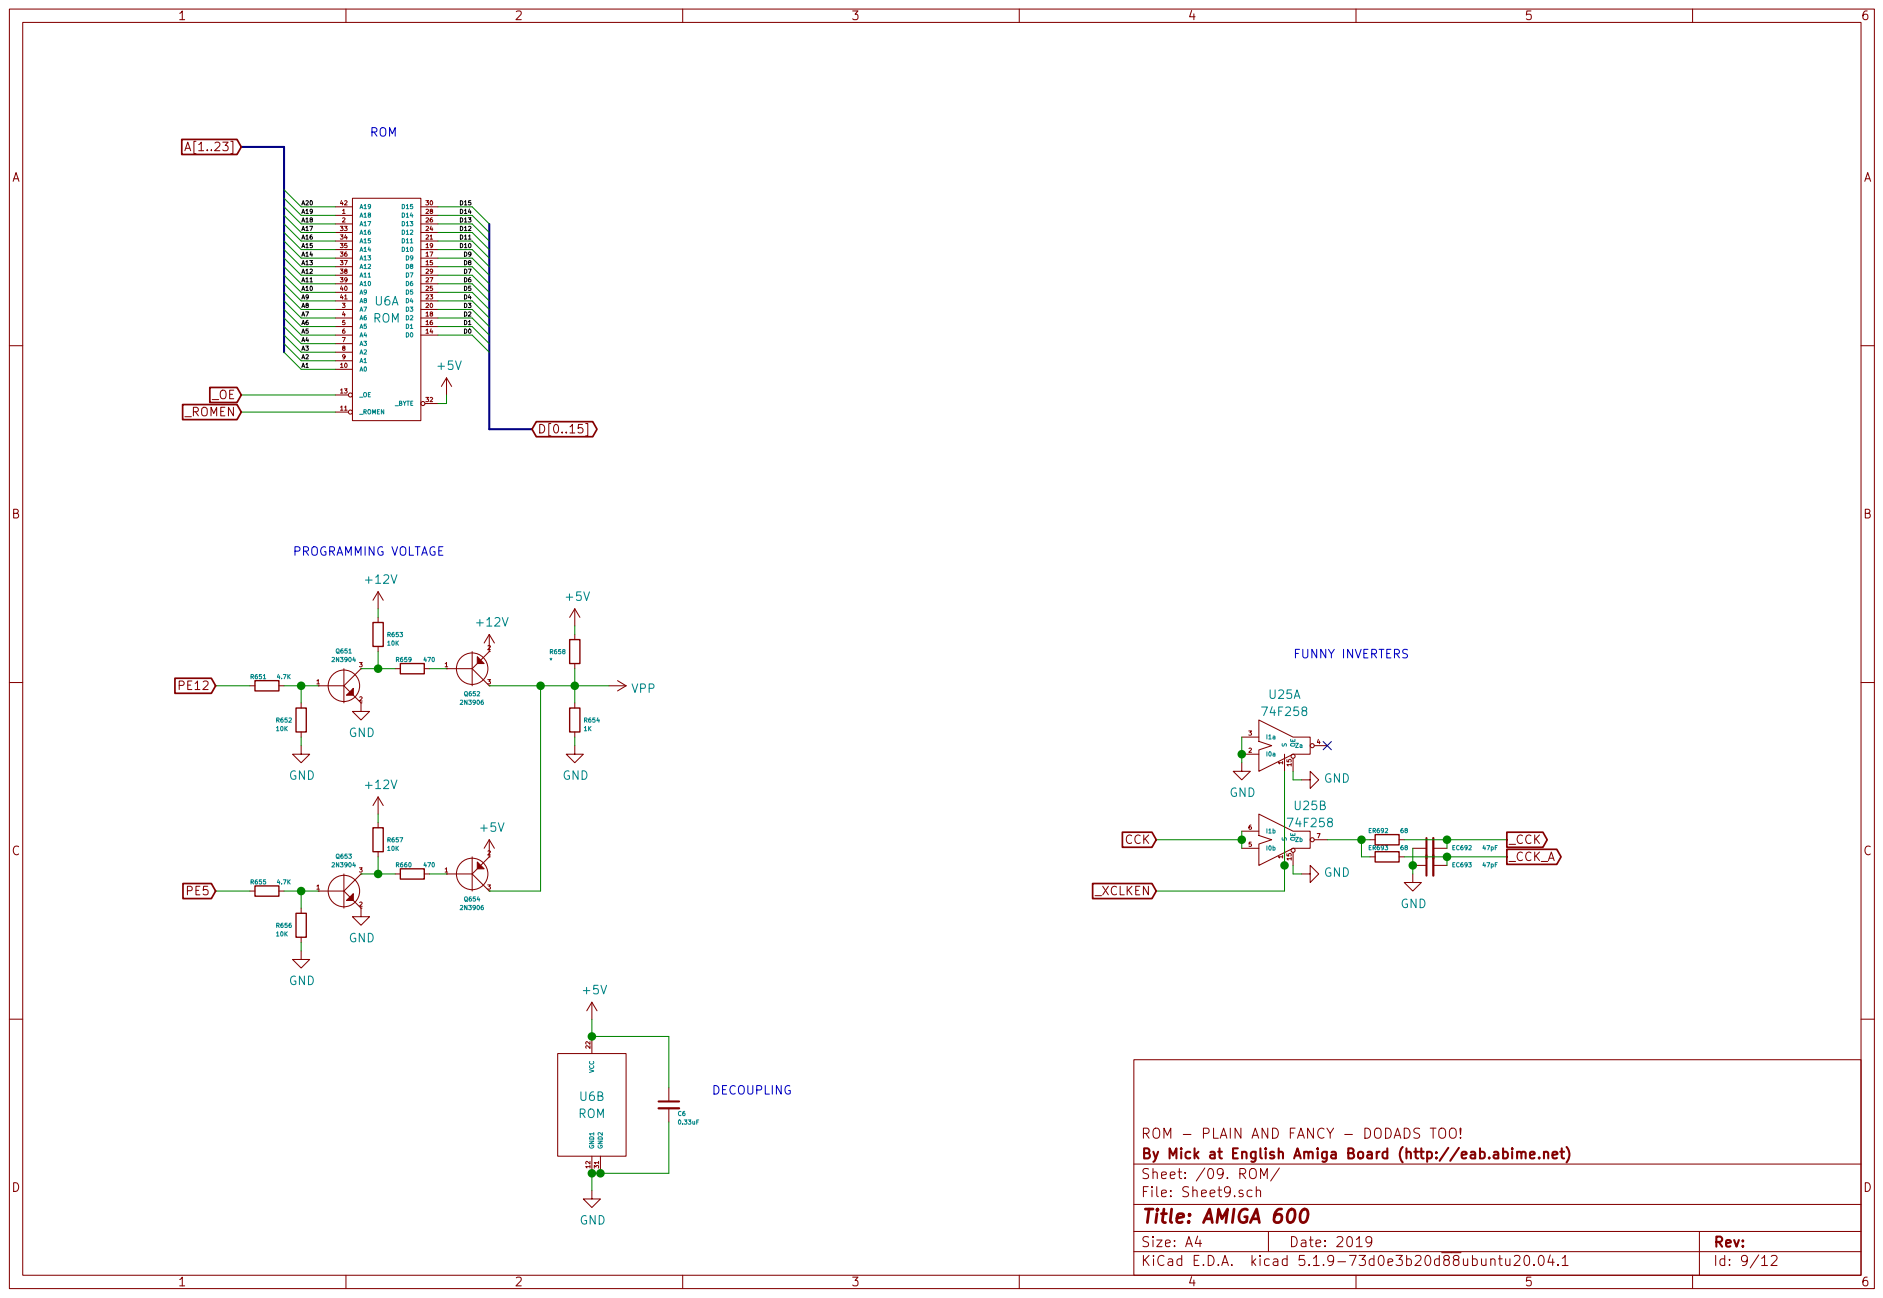
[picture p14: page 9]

File: Sheet9.sch Sheet: /09. ROM/ By Mick at English Amiga Board (http://eab.abime.net) ROM - PLAIN AND FANCY - DODADS TOO!

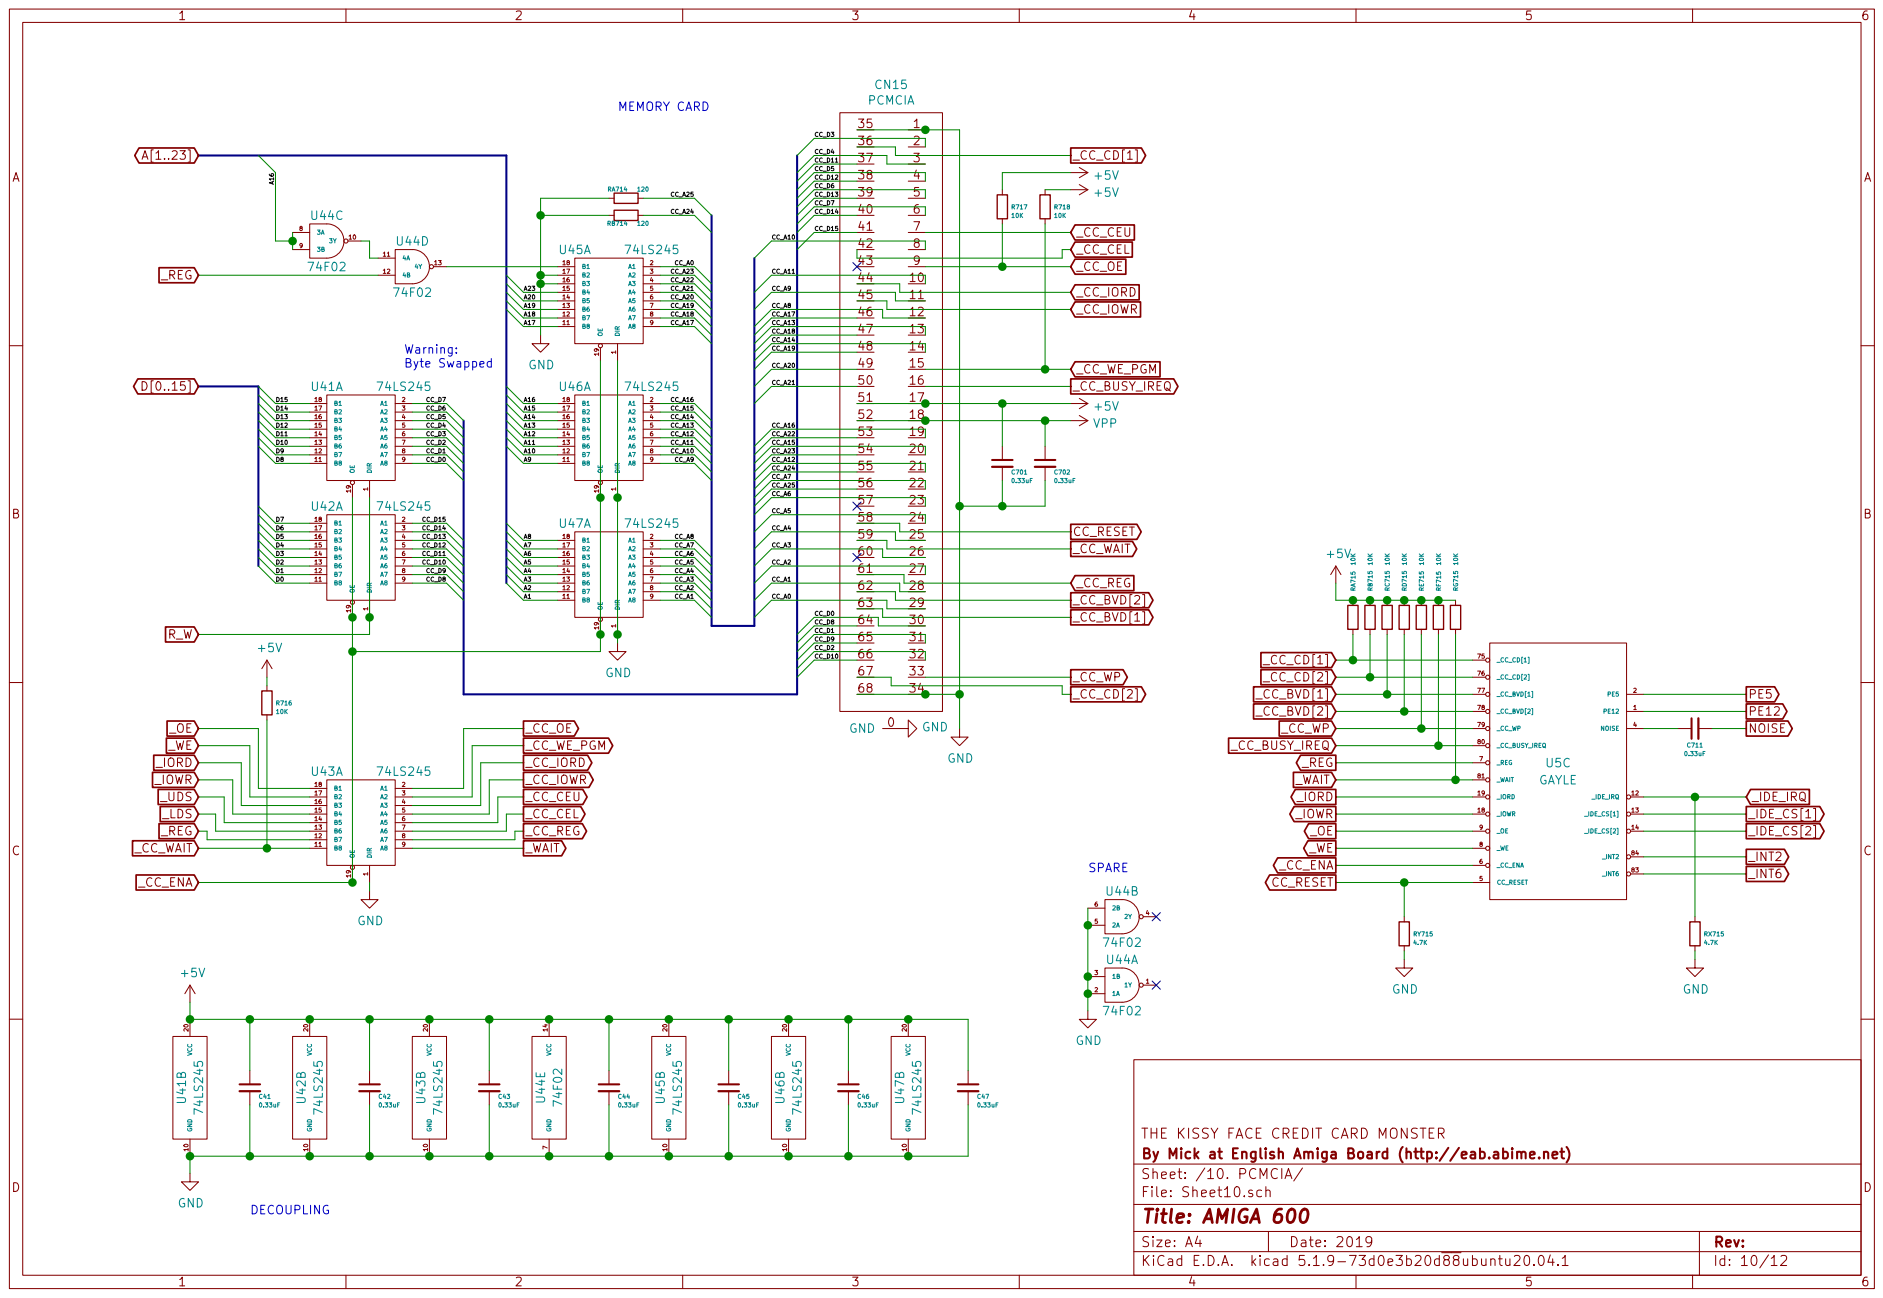
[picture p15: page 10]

File: Sheet10.sch Sheet: /10. PCMCIA/ By Mick at English Amiga Board (http://eab.abime.net) THE KISSY FACE CREDIT CARD MONSTER

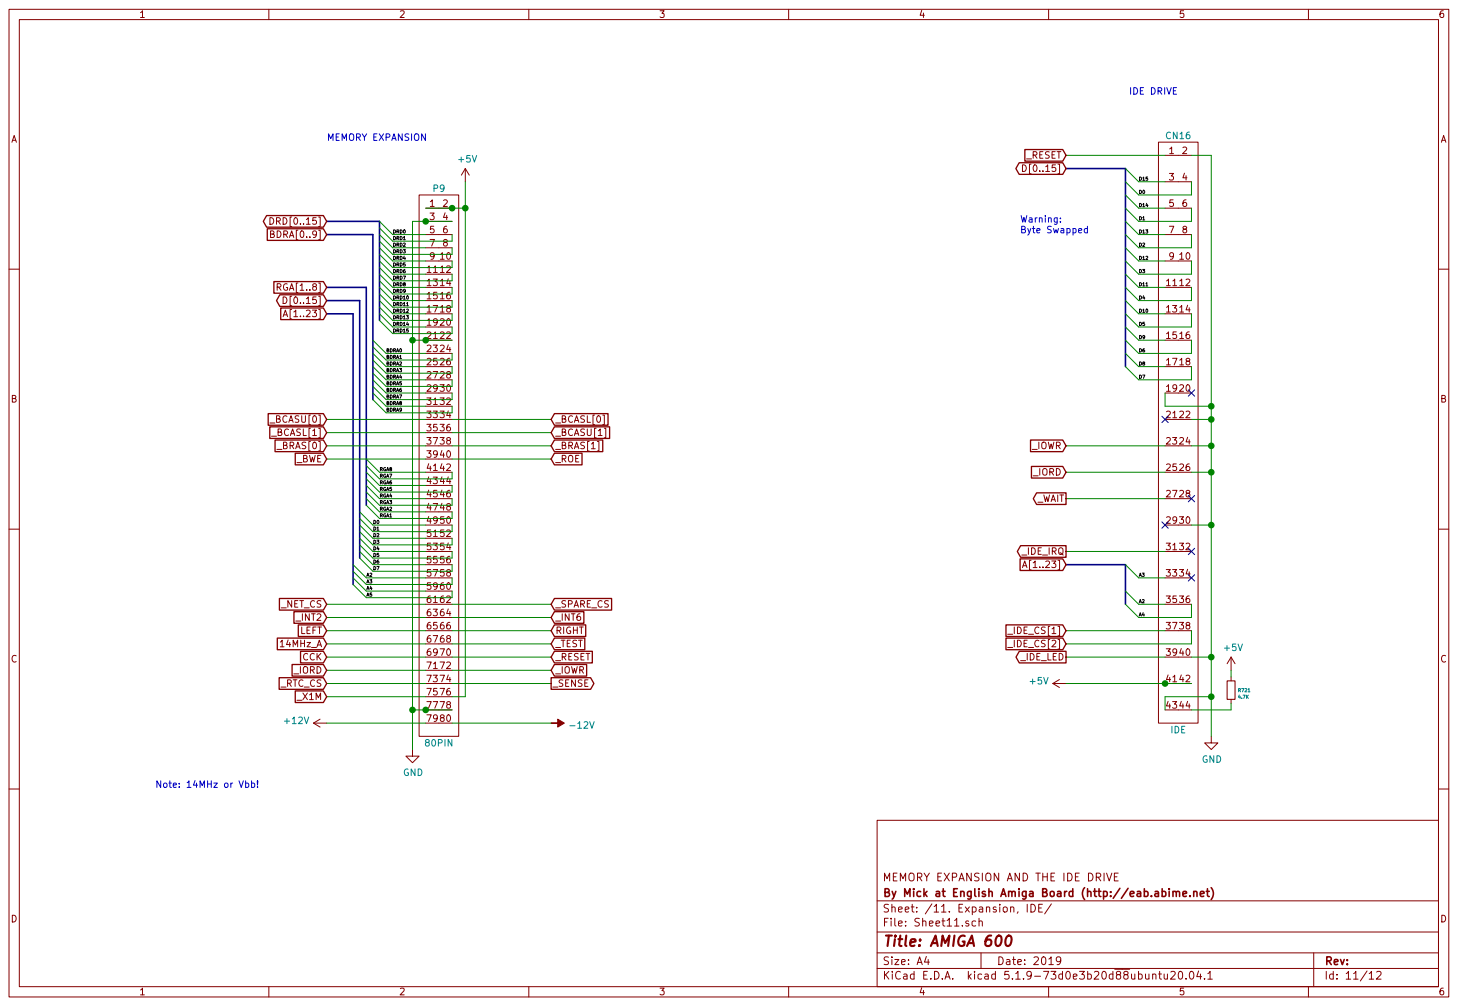
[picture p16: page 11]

By Mick at English Amiga Board (http://eab.abime.net) MEMORY EXPANSION AND THE IDE DRIVE

File: Sheet11.sch Sheet: /11. Expansion, IDE/
Id: 11/12 Title: AMIGA 600

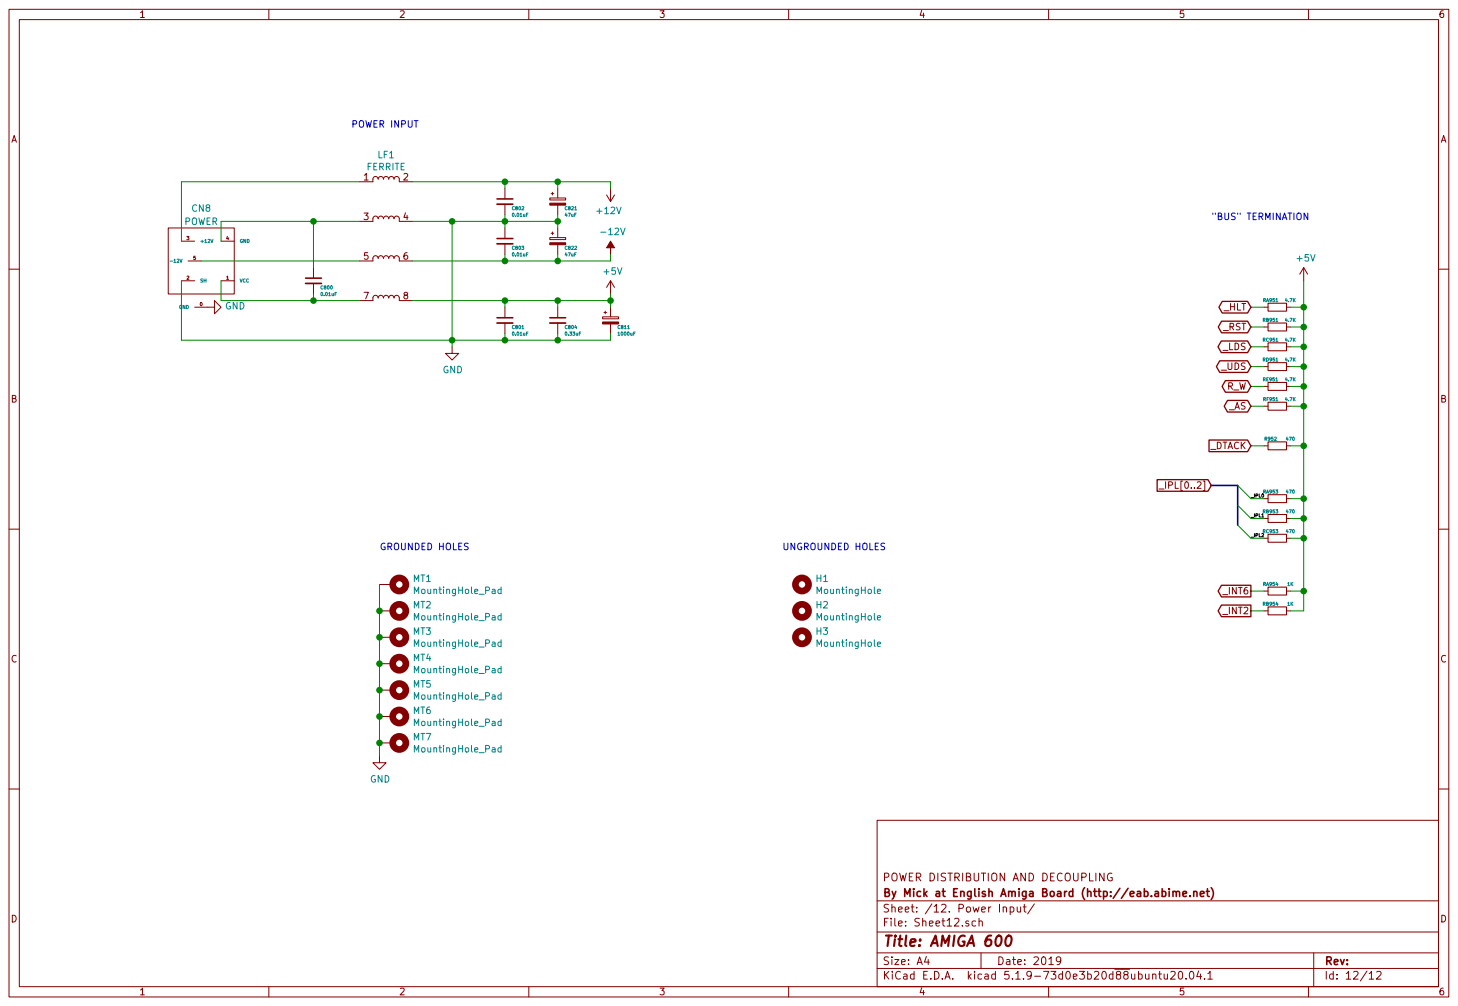
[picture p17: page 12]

By Mick at English Amiga Board (http://eab.abime.net) POWER DISTRIBUTION AND DECOUPLING

File: Sheet12.sch Sheet: /12. Power Input/
Id: 12/12 Title: AMIGA 600

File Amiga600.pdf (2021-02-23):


_LDS 35 R_W 36 _UDS 34

_DTACK 37

_BERR 24

_IPL2 25
_IPL1 26

_VPA 23




3A 11
3B 10 | ER374 68


Id: 5/12 Title: File: Sheet5.sch Sheet: /Sheet5/ CA12


Id: 6/12 Title: File: Sheet6.sch Sheet: /Sheet6/


9 CN11 FLOPPY 4 3 6 5 8 7

Id: 7/12 Title: File: Sheet7.sch Sheet: /Sheet7/


POWER UP RESET DUE TO DIE

Id: 8/12 Title: File: Sheet8.sch Sheet: /Sheet8/ C36


Id: 9/12 Title: File: Sheet9.sch Sheet: /Sheet9/


Id: 10/12 Title: File: Sheet10.sch Sheet: /Sheet10/



Id: 12/12 Title: File: Sheet12.sch Sheet: /Sheet12/

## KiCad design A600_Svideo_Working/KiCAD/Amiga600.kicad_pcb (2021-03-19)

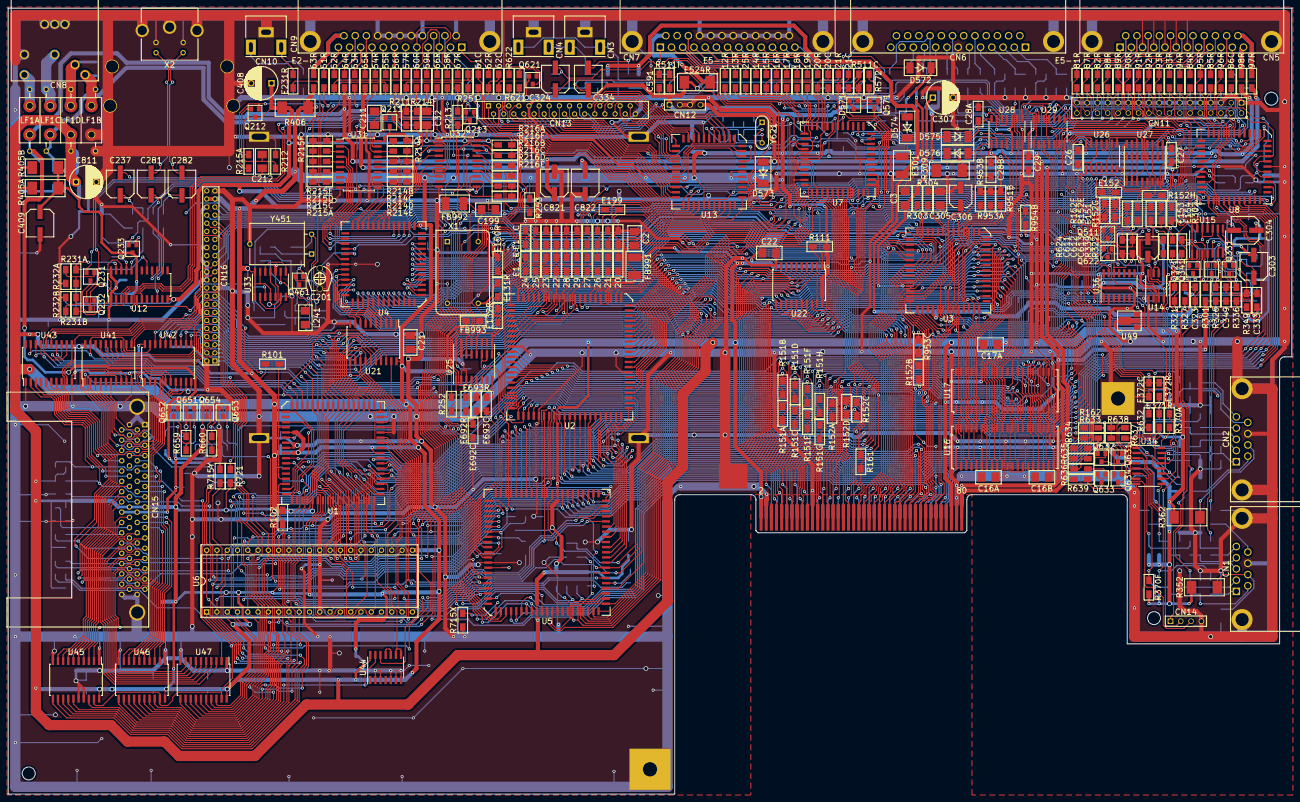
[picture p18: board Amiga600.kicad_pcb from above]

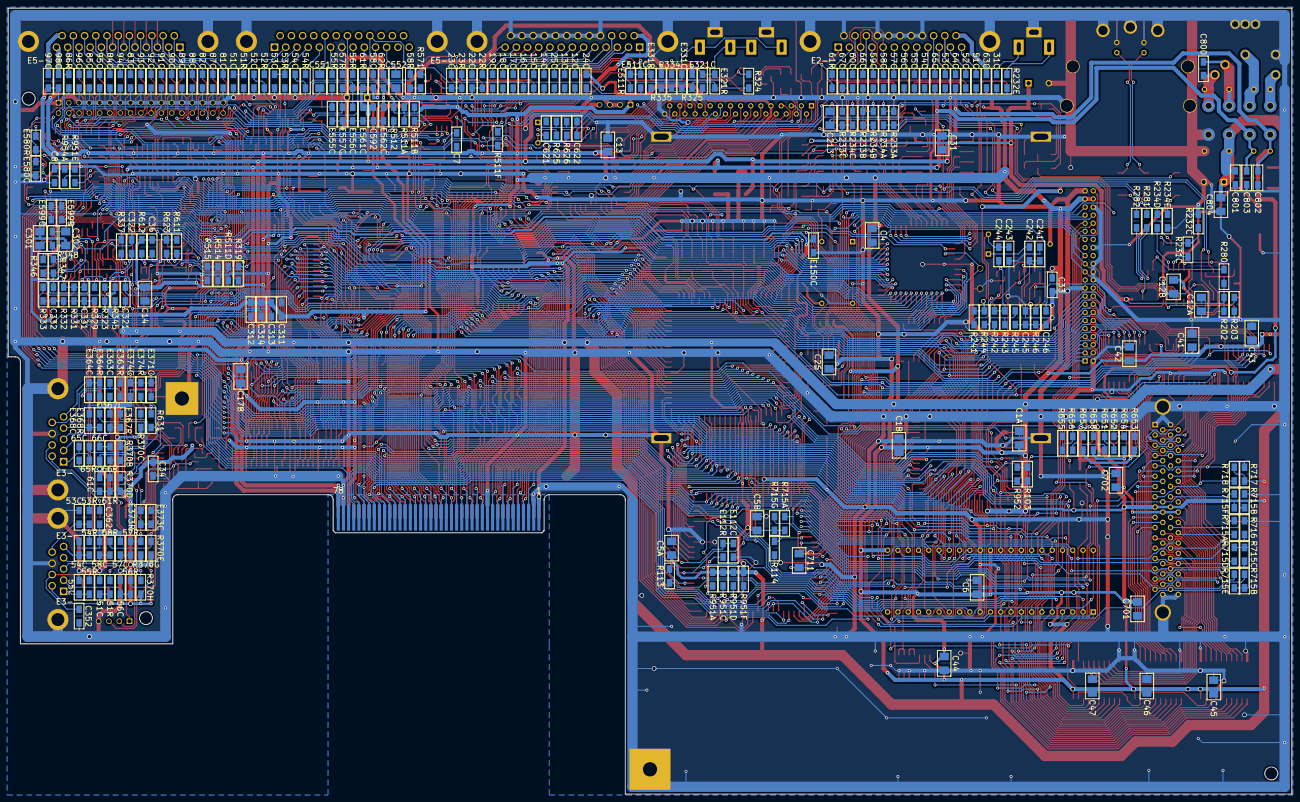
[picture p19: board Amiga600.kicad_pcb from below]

Board: 2 copper layers, 317.0 x 194.1 mm, 575 parts (259 on the bottom side), 566 nets.

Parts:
C2, C3, C4, C6, C13, C14, C21, C22, C25, C31, C32, C41, C42, C43, C44, C45, C46, C47, C199, C211, C212, C213, C301, C302, C305, C551, C552, C701, C702, C711, C804: 0.33uF; SMD_1210
C7, C8, C26, C27, C29, C33, C34, C36, C244, C246, C349, C591, C592, C613, C800, C801, C802, C803: 0.01uF; SMD_1206
C201: 47pf*; Trimmer
C237, C281, C282: 220uF; C_SMD_D6.3
C241, C245: 56pF; SMD_1206
C242: 15pF; SMD_1206
C243: 1000pF; SMD_1206
C303, C304, C324, C334: 22uF; C_SMD_D6.3
C306, C612: 10uF; C_SMD_D5
C307: 470uF; C_RAD_P5
C311, C312, C313, C314, C352: 0.047uF; SMD_1206
C321, C323, C331, C333: 3900pF; SMD_1206
C322, C332: 6800pF; SMD_1206
C362, C611: 0.1uF; SMD_1206
C408, C811: 1000uF; C_RAD_P5
C409: 100uF; C_SMD_D6.3
C621, C622: 22pF; SMD_1206
C821, C822: 47uF; C_SMD_D6.3
CA1, CA5, CA12, CA16, CA17: 0.33uF; SMD_1210
CA28: 0.01uF; SMD_1206
CB1, CB5, CB12, CB16, CB17: 0.33uF; SMD_1210
CB28: 0.01uF; SMD_1206
CN1, CN2: DB9P
CN3, CN4, CN10: RCA
CN5: DB23S
CN6: DB25P
CN7: DB25S
CN8: POWER; Power
CN9: DB23P
CN11: FLOPPY; Floppy
CN12, CN14: 4PIN; 1x04_P2.54
CN13: KEYBOARD; FFC-30
CN15: PCMCIA
CN16: IDE
D571: 1N914; SOT-23_Diode
D572, D573, D574, D575, D576: 1N4001; SMD_MELF
E151, E152, E153, E154: 47pF; SMD_1206
E199: 27; SMD_1206
E301: FB; SMD_1812
EC112, EC122, EC123, EC124, EC125, EC126, EC127: 22pF; SMD_1206
EC120: 0.33uF; SMD_1206
EC121, EC262: *; SMD_1206
EC128, EC129, EC150, EC258, EC259, EC260, EC692, EC693: 47pF; SMD_1206
EC231, EC251, EC252, EC253, EC254, EC255, EC256, EC257, EC261, EC266, EC267, EC511, EC512, EC513, EC514, EC515, EC516, EC517, EC518, EC519, EC520, EC521, EC522, EC523, EC525, EC551, EC552, EC558, EC580, EC581, EC582, EC583, EC584, EC585, EC586, EC587, EC588, EC589, EC590, EC591, EC592, EC593, EC594, EC595, EC596, EC599: 100pF; SMD_1206
EC263, EC264, EC265, EC524, EC557, EC561, EC562, EC597, EC598: 0.01uF; SMD_1206
EC321, EC331, EC355, EC356, EC357, EC358, EC365, EC366, EC367, EC368: 6800pF; SMD_1206
EC351, EC353, EC354, EC361, EC363, EC364, EC371, EC372, EC373, EC374, EC553, EC554, EC555, EC556: 470pF; SMD_1206
ER112, ER122, ER123, ER124, ER125, ER128, ER129, ER150, ER580, ER583, ER584, ER585, ER587, ER590, ER591, ER592, ER593, ER594, ER595, ER599: 27; SMD_1206
ER120, ER321, ER331: 0; SMD_1206
ER121: *; SMD_1206
ER126, ER127, ER253, ER254, ER255, ER256, ER557, ER561, ER562: 47; SMD_1206
ER131, ER132, ER251, ER252, ER257, ER261, ER262, ER266, ER267, ER351, ER353, ER354, ER355, ER356, ER357, ER358, ER361, ER363, ER364, ER365, ER366, ER367, ER368, ER371, ER372, ER373, ER374, ER511, ER512, ER513, ER514, ER515, ER516, ER517, ER518, ER519, ER520, ER521, ER522, ER523, ER525, ER551, ER552, ER553, ER554, ER555, ER556, ER558, ER581, ER582, ER586, ER588, ER589, ER596, ER692, ER693: 68; SMD_1206
ER231: FB100; SMD_1206
ER258, ER259, ER260, ER263, ER264, ER265, ER597, ER598: FB200; SMD_1206
ER524: 47; SMD_2512
FB991, FB992: FB; SMD_1812
FB993: FB; SMD_1206
H1, H2, H3: MountingHole; Hole
L241: 1.2uH; SMD_1210
LF1: FERRITE; Ferrite
MT1, MT2, MT3, MT4: MountingHole_Pad; MT1-4
MT5: MountingHole_Pad; MT5
MT6: MountingHole_Pad; MT6
MT7: MountingHole_Pad; MT7
P9: 80PIN; Expansion
Q211, Q212, Q213, Q231, Q232, Q233, Q461, Q511, Q571, Q621, Q622, Q651, Q653: 2N3904; SOT-23
Q321, Q331: MPF102; SOT-23
Q341, Q631, Q632, Q633, Q634, Q652, Q654: 2N3906; SOT-23
R101, R102, R103, R244, R303, R304, R319, R324, R334, R512, R621, R654: 1K; SMD_1206
R111, R161, R162, R515, R659, R660, R952: 470; SMD_1206
R113, R114: 27; SMD_1206
R202, R246, R624, R625, R626, R658: *; SMD_1206
R203: 0; SMD_1206
R211, R212, R213: 150; SMD_1206
R241, R251, R252, R253, R348, R514, R632, R634, R636, R638, R651, R655, R721: 4.7K; SMD_1206
R242: 6.8K; SMD_1206
R243, R322, R323, R327, R329, R332, R333, R337, R339, R346, R572, R623, R631, R633, R635, R637, R652, R653, R656, R657, R716, R717, R718: 10K; SMD_1206
R245, R347, R571: 2.7K; SMD_1206
R280: 2.61K; SMD_1206
R281, R282: 75; SMD_1206
R301, R302: 10; SMD_1206
R309: 1; SMD_2512
R321, R331: 680; SMD_1206
R325, R335: 2K; SMD_1206
R326, R336: 470K; SMD_1206
R345: 22K; SMD_1206
R349: 33K; SMD_1206
R352, R362, R406: 4.7; SMD_2512
R611: 1M; SMD_1206
R612: 47K; SMD_1206
R622, R639: 100; SMD_1206
RA151, RA152: 68; SMD_1206
RA214, RA215, RA216: 270; SMD_1206
RA231, RA954: 1K; SMD_1206
RA232: 33K; SMD_1206
RA233: 150; SMD_1206
RA234: 75; SMD_1206
RA370, RA951: 4.7K; SMD_1206
RA405: 1; SMD_2512
RA511, RA715: 10K; SMD_1206
RA714: 120; SMD_1206
RA953: 470; SMD_1206
RB151: 68; SMD_1206
RB152: 27; SMD_1206
RB214, RB215, RB216, RB231, RB954: 1K; SMD_1206
RB232: 33K; SMD_1206
RB233: 150; SMD_1206
RB234: 75; SMD_1206
RB370, RB951: 4.7K; SMD_1206
RB405: 1; SMD_2512
RB511, RB715: 10K; SMD_1206
RB714: 120; SMD_1206
RB953: 470; SMD_1206
RC151: 68; SMD_1206
RC152: 27; SMD_1206
RC214, RC215, RC216: 2K; SMD_1206
RC231: 1K; SMD_1206
RC232: 33K; SMD_1206
RC233: 150; SMD_1206
RC234: 75; SMD_1206
RC370, RC951: 4.7K; SMD_1206
RC511, RC715: 10K; SMD_1206
RC953: 470; SMD_1206
RD151: 68; SMD_1206
RD152: 27; SMD_1206
RD214, RD215, RD216: 4K; SMD_1206
RD234: 43; SMD_1206
RD370, RD951: 4.7K; SMD_1206
RD511: 1K; SMD_1206
RD715: 10K; SMD_1206
RE151: 68; SMD_1206
RE152: 27; SMD_1206
RE214, RE215, RE216: 8K; SMD_1206
RE232: 75; SMD_1206
RE234: 240; SMD_1206
RE370, RE951: 4.7K; SMD_1206
RE715: 10K; SMD_1206
RF151: 68; SMD_1206
RF152: 27; SMD_1206
RF214, RF215, RF216: 330; SMD_1206
RF370, RF951: 4.7K; SMD_1206
RF511, RF715: 10K; SMD_1206
RG151: 68; SMD_1206
RG152: 27; SMD_1206
RG370: 4.7K; SMD_1206
RG715: 10K; SMD_1206
RH151: 68; SMD_1206
RH152: 27; SMD_1206
RH370: 4.7K; SMD_1206
RI511: 10K; SMD_1206
RX715: 4.7K; SMD_1206
RY715: 4.7K; SMD_1206
U1: MC68000; PLCC-68
U2: AGNUS; PLCC-84
U3: PAULA; PLCC-52
U4: DENISE; PLCC-52
U5: GAYLE; PLCC-84
U6: ROM; DIP-42
U7, U8: 8520; PLCC-44
U12: CXA2075M; SOP-24
U13: 6570; PLCC-44
U14: NE555; SOIC-8
U15: TL084; SOIC-14
U16, U17: 256Kx16; SOJ-40
U21, U22, U41, U42, U43, U45, U46, U47: 74LS245; SOIC-20W
U25: 74F258; SOIC-16-DUAL
U26: 74F00; SOIC-14
U27: 74F139; SOIC-16-DUAL
U28: 1488; SOIC-14
U29: 1489; SOIC-14
U31, U32: 74HCT244; SOIC-20W
U33: 74LS74A; SOIC-14
U34: 74LS157; SOIC-16
U36: 74F27; SOIC-14
U44: 74F02; SOIC-14
U49: RH5VA43A; SOT-89
X1: 28.37516MHz; Oscillator
X2: MINI-DIN; S-Video
Y451: 4.433619MHz; Crystal
Y621: 3MHz; Resonator

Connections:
7MHz: EC123.2, ER123.2, U1.15
7MHz_A: C201.1, EC122.2, ER122.2, U4.38
14MHz: E199.2, EC121.2, ER121.2, U5.22
14MHz_A: EC120.2, ER120.2, P9.67
+5V: C4.1, C6.1, C7.1, C8.1, C13.1, C14.1, C21.1, C22.1, C26.1, C27.1, C29.1, C33.1, C34.1, C36.1, C41.1, C42.1, C43.1, C44.1, C45.1, C46.1, C47.1, C591.1, C701.1, C801.1, C804.1, C811.1, CA1.1, CA5.1, CA16.1, CA17.1, CB1.1, CB5.1, CB16.1, CB17.1, CN12.1, CN13.9, CN15.17, CN15.51, CN16.41, CN16.42, D572.1, D573.1, D574.1, EC524.2, ER263.2, ER524.2, ER598.1, FB991.1, FB992.1, FB993.1, LF1.8, P9.1, P9.2, P9.76, Q631.2, Q632.2, Q633.2, Q634.2, Q654.2, R101.1, R102.1, R103.1, R111.1, R251.1, R252.1, R253.1, R309.1, R319.2, R352.1, R362.1, R406.1, R512.1, R514.1, R611.1, R612.1, R623.1, R631.1, R633.1, R635.1, R637.1, R639.1, R658.1, R716.1, R717.1, R718.1, R721.1, R952.2, RA370.1, RA405.2, RA511.1, RA715.1, RA951.2, RA953.2, RA954.2, RB370.1, RB405.2, RB511.1, RB715.1, RB951.2, RB953.2, RB954.2, RC370.1, RC511.1, RC715.1, RC951.2, RC953.2, RD370.1, RD511.1, RD715.1, RD951.2, RE370.1, RE715.1, RE951.2, RF370.1, RF511.1, RF715.1, RF951.2, RG370.1, RG715.1, RH370.1, RI511.1, U1.14, U1.18, U1.31, U1.52, U4.21, U5.20, U5.62, U6.22, U6.32, U7.22, U8.22, U13.1, U13.24, U13.33, U13.44, U14.4, U14.8, U16.1, U16.6, U16.20, U17.1, U17.6, U17.20, U21.20, U22.20, U26.14, U27.16, U28.5, U28.10, U28.13, U29.14, U33.1, U33.4, U33.10, U33.13, U33.14, U34.16, U36.14, U41.20, U42.20, U43.20, U44.14, U45.20, U46.20, U47.20, U49.2
+12V: C592.1, C802.1, C821.1, CN12.4, D575.2, EC561.1, ER264.2, ER561.1, ER597.1, LF1.2, P9.79, Q652.2, R301.1, R653.1, R657.1
+AV: C301.1, C303.1, Q341.2, R301.2, R347.1, U15.4
+VID: C31.1, C32.1, C408.1, CA12.1, Q211.3, Q212.3, Q213.3, R202.1, R241.1, R244.1, R280.1, R406.2, RA214.1, RA215.1, RA216.1, U12.12, U31.20, U32.20
+VOUT: C409.1, CB12.1, Q231.3, Q232.3, Q233.3, RA405.1, RB405.1, U12.19
-12V: C803.2, C822.2, D576.1, EC562.1, ER265.2, ER562.1, LF1.6, P9.80, R302.2
-AV: C302.2, C304.2, R302.1, R348.2, U15.11
/06. Serial, Parallel/PPD0: ER512.1, U7.12
/06. Serial, Parallel/PPD1: ER513.1, U7.13
/06. Serial, Parallel/PPD2: ER514.1, U7.14
/06. Serial, Parallel/PPD3: ER515.1, U7.15
/06. Serial, Parallel/PPD4: ER516.1, U7.16
/06. Serial, Parallel/PPD5: ER517.1, U7.17
/06. Serial, Parallel/PPD6: ER518.1, U7.18
/06. Serial, Parallel/PPD7: ER519.1, U7.19
/10. PCMCIA/CC_A0: CN15.29, U45.2
/10. PCMCIA/CC_A1: CN15.28, U47.9
/10. PCMCIA/CC_A2: CN15.27, U47.8
/10. PCMCIA/CC_A3: CN15.26, U47.7
/10. PCMCIA/CC_A4: CN15.25, U47.6
/10. PCMCIA/CC_A5: CN15.24, U47.5
/10. PCMCIA/CC_A6: CN15.23, U47.4
/10. PCMCIA/CC_A7: CN15.22, U47.3
/10. PCMCIA/CC_A8: CN15.12, U47.2
/10. PCMCIA/CC_A9: CN15.11, U46.9
/10. PCMCIA/CC_A10: CN15.8, U46.8
/10. PCMCIA/CC_A11: CN15.10, U46.7
/10. PCMCIA/CC_A12: CN15.21, U46.6
/10. PCMCIA/CC_A13: CN15.13, U46.5
/10. PCMCIA/CC_A14: CN15.14, U46.4
/10. PCMCIA/CC_A15: CN15.20, U46.3
/10. PCMCIA/CC_A16: CN15.19, U46.2
/10. PCMCIA/CC_A17: CN15.46, U45.9
/10. PCMCIA/CC_A18: CN15.47, U45.8
/10. PCMCIA/CC_A19: CN15.48, U45.7
/10. PCMCIA/CC_A20: CN15.49, U45.6
/10. PCMCIA/CC_A21: CN15.50, U45.5
/10. PCMCIA/CC_A22: CN15.53, U45.4
/10. PCMCIA/CC_A23: CN15.54, U45.3
/10. PCMCIA/CC_A24: CN15.55, RB714.2
/10. PCMCIA/CC_A25: CN15.56, RA714.2
/10. PCMCIA/CC_D0: CN15.30, U41.9
/10. PCMCIA/CC_D1: CN15.31, U41.8
/10. PCMCIA/CC_D2: CN15.32, U41.7
/10. PCMCIA/CC_D3: CN15.2, U41.6
/10. PCMCIA/CC_D4: CN15.3, U41.5
/10. PCMCIA/CC_D5: CN15.4, U41.4
/10. PCMCIA/CC_D6: CN15.5, U41.3
/10. PCMCIA/CC_D7: CN15.6, U41.2
/10. PCMCIA/CC_D8: CN15.64, U42.9
/10. PCMCIA/CC_D9: CN15.65, U42.8
/10. PCMCIA/CC_D10: CN15.66, U42.7
/10. PCMCIA/CC_D11: CN15.37, U42.6
/10. PCMCIA/CC_D12: CN15.38, U42.5
/10. PCMCIA/CC_D13: CN15.39, U42.4
/10. PCMCIA/CC_D14: CN15.40, U42.3
/10. PCMCIA/CC_D15: CN15.41, U42.2
A1: U1.32, U2.60, U6.10, U47.11
A2: CN16.35, P9.57, U1.33, U2.61, U6.9, U47.12
A3: CN16.33, P9.58, U1.34, U2.62, U6.8, U47.13
A4: CN16.36, P9.59, U1.35, U2.63, U6.7, U47.14
A5: P9.60, U1.36, U2.64, U6.6, U47.15
A6: U1.37, U2.65, U6.5, U47.16
A7: U1.38, U2.66, U6.4, U47.17
A8: U1.39, U2.67, U6.3, U7.42, U8.42, U47.18
A9: U1.40, U2.68, U6.41, U7.41, U8.41, U46.11
A10: U1.41, U2.69, U6.40, U7.39, U8.39, U46.12
A11: U1.42, U2.70, U6.39, U7.38, U8.38, U46.13
A12: U1.43, U2.71, U5.41, U6.38, U46.14
A13: U1.44, U2.72, U5.42, U6.37, U46.15
A14: U1.45, U2.73, U5.43, U6.36, U46.16
A15: U1.46, U2.74, U5.44, U6.35, U46.17
A16: U1.47, U2.75, U5.46, U6.34, U44.8, U44.9, U46.18
A17: U1.48, U2.76, U5.47, U6.33, U45.11
A18: U1.49, U2.77, U5.48, U6.2, U45.12
A19: U1.50, U2.59, U5.49, U6.1, U45.13
A20: U1.51, U2.35, U5.50, U6.42, U45.14
A21: U1.53, U5.51
A22: U1.54, U5.52
A23: U1.55, U5.53, U45.15
AB: ER258.1, RC234.2
AG: ER259.1, RB234.2
AR: ER260.1, RA234.2
AUDIN: C551.2, R339.1
AUDIO: C301.2, C302.1, C303.2, C304.1, C311.2, C312.2, C313.2, C314.2, C323.2, C333.2, C349.2, E301.1, R325.2, R335.2, R345.2, U3.37
AUDOUT: C324.2, C552.2, R324.1
AVREF: C305.1, C306.1, R303.2, R304.1, U15.10, U15.12
BDRA0: P9.23, RA151.2, U16.16, U17.16
BDRA1: P9.24, RB151.2, U16.17, U17.17
BDRA2: P9.25, RC151.2, U16.18, U17.18
BDRA3: P9.26, RD151.2, U16.19, U17.19
BDRA4: P9.27, RE151.2, U16.22, U17.22
BDRA5: P9.28, RF151.2, U16.23, U17.23
BDRA6: P9.29, RG151.2, U16.24, U17.24
BDRA7: P9.30, RH151.2, U16.25, U17.25
BDRA8: P9.31, RA152.2, U16.26, U17.26
B[0]: ER257.1, RE216.1, U32.12
B[3]: ER256.1, RB216.1, U32.18
CCK: EC127.2, ER127.2, P9.69, U3.31, U4.39, U5.23, U25.5, U25.6, U32.11
CCKQ: EC129.2, ER129.2, U3.32
CCKQ_A: EC128.2, ER128.2, R246.1, U33.3, U34.1
CCK_A: EC126.2, ER126.2, U26.2, U26.12, U27.1, U27.15
CCK_B: ER266.2, U32.9
CC_RESET: CN15.58, RY715.1, U5.5
D0: CN16.4, P9.49, U1.5, U6.14, U7.36, U22.11, U42.11
D1: CN16.6, P9.50, U1.4, U6.16, U7.35, U22.12, U42.12
D2: CN16.8, P9.51, U1.3, U6.18, U7.34, U22.13, U42.13
D3: CN16.10, P9.52, U1.2, U6.20, U7.33, U22.14, U42.14
D4: CN16.12, P9.53, U1.1, U6.23, U7.32, U22.15, U42.15
D5: CN16.14, P9.54, U1.68, U6.25, U7.31, U22.16, U42.16
D6: CN16.16, P9.55, U1.67, U6.27, U7.30, U22.17, U42.17
D7: CN16.18, P9.56, U1.66, U6.29, U7.29, U22.18, U42.18
D8: CN16.17, U1.65, U5.61, U6.15, U8.36, U21.18, U41.11
D9: CN16.15, U1.64, U5.60, U6.17, U8.35, U21.17, U41.12
D10: CN16.13, U1.63, U5.59, U6.19, U8.34, U21.16, U41.13
D11: CN16.11, U1.62, U5.58, U6.21, U8.33, U21.15, U41.14
D12: CN16.9, U1.61, U5.57, U6.24, U8.32, U21.14, U41.15
D13: CN16.7, U1.60, U5.56, U6.26, U8.31, U21.13, U41.16
D14: CN16.5, U1.59, U5.55, U6.28, U8.30, U21.12, U41.17
D15: CN16.3, U1.58, U5.54, U6.30, U8.29, U21.11, U41.18
DIR: ER593.1, U8.13
DKWE: U3.42, U5.69
DMAL: U2.18, U3.12
DRA0: RA151.1, U2.42
DRA1: RB151.1, U2.43
DRA2: RC151.1, U2.44
DRA3: RD151.1, U2.45
DRA4: RE151.1, U2.46
DRA5: RF151.1, U2.47
DRA6: RG151.1, U2.48
DRA7: RH151.1, U2.49
DRA8: RA152.1, U2.50
DRA9: U2.55, U25.10, U25.11, U26.13
DRD0: P9.5, U2.14, U3.10, U4.8, U16.2, U17.2, U22.9
DRD1: P9.6, U2.13, U3.9, U4.6, U16.3, U17.3, U22.8
DRD2: P9.7, U2.12, U3.7, U4.5, U16.4, U17.4, U22.7
DRD3: P9.8, U2.11, U3.6, U4.4, U16.5, U17.5, U22.6
DRD4: P9.9, U2.10, U3.5, U4.3, U16.7, U17.7, U22.5
DRD5: P9.10, U2.9, U3.4, U4.2, U16.8, U17.8, U22.4
DRD6: P9.11, U2.8, U3.3, U4.1, U16.9, U17.9, U22.3
DRD7: P9.12, U2.7, U3.2, U4.52, U16.10, U17.10, U22.2
DRD8: P9.13, U2.6, U3.1, U4.51, U16.31, U17.31, U21.2
DRD9: P9.14, U2.5, U3.52, U4.50, U16.32, U17.32, U21.3
DRD10: P9.15, U2.4, U3.51, U4.49, U16.33, U17.33, U21.4
DRD11: P9.16, U2.3, U3.50, U4.48, U16.34, U17.34, U21.5
DRD12: P9.17, U2.2, U3.49, U4.46, U16.36, U17.36, U21.6
DRD13: P9.18, U2.1, U3.48, U4.45, U16.37, U17.37, U21.7
DRD14: P9.19, U2.84, U3.46, U4.44, U16.38, U17.38, U21.8
DRD15: P9.20, U2.83, U3.45, U4.43, U16.39, U17.39, U21.9
E: EC112.2, ER112.2, R626.1, U7.27, U8.27
GND: C2.2, C3.2, C4.2, C6.2, C7.2, C8.2, C13.2, C14.2, C21.2, C22.2, C25.2, C26.2, C27.2, C29.2, C31.2, C32.2, C33.2, C34.2, C36.2, C41.2, C42.2, C43.2, C44.2, C45.2, C46.2, C47.2, C199.2, C201.2, C241.2, C243.2, C245.2, C305.2, C306.2, C307.2, C352.1, C362.1, C408.2, C409.2, C591.2, C592.2, C611.2, C612.2, C613.2, C621.1, C622.1, C701.2, C702.2, C801.2, C802.2, C803.1, C804.2, C811.2, C821.2, C822.1, CA1.2, CA5.2, CA12.2, CA16.2, CA17.2, CA28.2, CB1.2, CB5.2, CB12.2, CB16.2, CB17.2, CB28.2, CN1.0, CN1.8, CN2.0, CN2.8, CN3.3, CN4.3, CN5.0, CN5.3, CN5.4, CN5.5, CN5.6, CN5.7, CN6.0, CN6.7, CN7.0, CN7.17, CN7.18, CN7.19, CN7.20, CN7.21, CN7.22, CN7.23, CN7.24, CN7.25, CN8.0, CN8.2, CN9.0, CN9.13, CN9.16, CN9.17, CN9.18, CN9.19, CN9.20, CN10.3, CN11.1, CN11.5, CN11.7, CN11.9, CN11.11, CN11.13, CN11.15, CN11.17, CN11.19, CN11.21, CN11.23, CN11.25, CN11.27, CN11.29, CN11.31, CN11.33, CN12.2, CN12.3, CN13.30, CN14.4, CN15.0, CN15.1, CN15.34, CN15.35, CN15.68, CN16.2, CN16.19, CN16.22, CN16.24, CN16.26, CN16.30, CN16.40, CN16.43, D571.2, E151.2, E152.2, E153.2, E154.2, E301.2, EC112.1, EC120.1, EC121.1, EC122.1, EC123.1, EC124.1, EC125.1, EC126.1, EC127.1, EC128.1, EC129.1, EC150.1, EC231.1, EC251.1, EC252.1, EC253.1, EC254.1, EC255.1, EC256.1, EC257.1, EC258.1, EC259.1, EC260.1, EC261.2, EC262.2, EC263.2, EC264.2, EC265.2, EC266.2, EC267.2, EC321.1, EC331.1, EC351.1, EC353.1, EC354.1, EC355.2, EC356.2, EC357.2, EC358.2, EC361.1, EC363.1, EC364.1, EC365.2, EC366.2, EC367.2, EC368.2, EC371.1, EC372.1, EC373.1, EC374.1, EC511.1, EC512.1, EC513.1, EC514.1, EC515.1, EC516.1, EC517.1, EC518.1, EC519.1, EC520.2, EC521.2, EC522.2, EC523.2, EC524.1, EC525.2, EC551.1, EC552.2, EC553.1, EC554.2, EC555.2, EC556.2, EC557.1, EC558.2, EC561.2, EC562.2, EC580.1, EC581.1, EC582.1, EC583.1, EC584.1, EC585.1, EC586.1, EC587.1, EC588.1, EC589.1, EC590.1, EC591.1, EC592.1, EC593.1, EC594.1, EC595.1, EC596.1, EC597.1, EC598.1, EC599.1, EC692.1, EC693.1, L241.2, LF1.4, MT1.1, MT2.1, MT3.1, MT4.1, MT5.1, MT6.1, MT7.1, P9.3, P9.4, P9.21, P9.22, P9.77, P9.78, Q461.2, Q511.2, Q571.2, Q621.2, Q622.2, Q651.2, Q653.2, R161.2, R162.2, R203.2, R211.2, R212.2, R213.2, R242.2, R304.2, R572.2, R652.2, R654.2, R656.2, RA232.2, RA233.2, RA714.1, RB232.2, RB233.2, RB714.1, RC232.2, RC233.2, RE232.2, RE234.2, RF214.1, RF215.1, RF216.1, RX715.2, RY715.2, U1.16, U1.17, U1.56, U1.57, U2.41, U2.58, U2.82, U3.8, U4.40, U5.3, U5.24, U5.45, U5.66, U6.12, U6.31, U7.1, U8.1, U12.1, U12.24, U13.13, U14.1, U16.21, U16.35, U16.40, U17.21, U17.35, U17.40, U21.10, U22.10, U25.2, U25.3, U25.8, U25.15, U26.7, U27.8, U28.7, U29.7, U31.1, U31.10, U31.19, U32.1, U32.10, U32.19, U33.7, U34.8, U34.15, U36.7, U41.10, U42.10, U43.1, U43.10, U44.2, U44.3, U44.5, U44.6, U44.7, U45.1, U45.10, U45.16, U45.17, U46.1, U46.10, U47.1, U47.10, U49.3, X1.7, X2.0, X2.1, X2.2, Y451.3
G[3]: ER255.1, RB215.1, U31.9
LEFT: C321.1, P9.65, R321.1, U3.34, U15.13
M0H: EC372.2, ER372.2, U4.10
M0V: EC371.2, ER371.2, U4.41
M1H: EC374.2, ER374.2, U4.9
M1V: EC373.2, ER373.2, U4.42
MONO: R327.1, R337.2, R345.1
NOISE: C711.2, R329.1
unnamed: C2.1, FB991.2, U2.15
unnamed: C3.1, C307.1, R303.1, R309.2, U3.30
unnamed: C25.1, FB993.2, U25.16
unnamed: C199.1, FB992.2, X1.14
unnamed: C211.1, Q211.2, R211.1
unnamed: C211.2, U12.2
unnamed: C212.1, Q212.2, R212.1
unnamed: C212.2, U12.3
unnamed: C213.1, Q213.2, R213.1
unnamed: C213.2, U12.4
unnamed: C237.1, RD234.2, RE234.1
unnamed: C237.2, ER231.1
unnamed: C241.1, C242.1, R241.2, U33.9
unnamed: C242.2, Y451.1
unnamed: C243.1, C244.1, L241.1, Y451.2
unnamed: C244.2, Q461.1, R242.1, R243.1
unnamed: C245.1, C246.1, R245.2, R246.2
unnamed: C246.2, U12.6
unnamed: C281.1, R281.2
unnamed: C281.2, X2.3
unnamed: C282.1, R282.2
unnamed: C282.2, X2.4
unnamed: C311.1, ER354.1, U3.35
unnamed: C312.1, ER353.1, U3.36
unnamed: C313.1, ER364.1, U3.38
unnamed: C314.1, ER363.1, U3.39
unnamed: C321.2, Q321.1, R321.2, R322.1, U15.14
unnamed: C322.1, C324.1, R327.2, U15.1, U15.2
unnamed: C322.2, R322.2, R323.1
unnamed: C323.1, Q321.2, R323.2, U15.3
unnamed: C331.2, Q331.1, R331.2, R332.1, U15.8
unnamed: C332.1, C334.1, R337.1, U15.6, U15.7
unnamed: C332.2, R332.2, R333.1
unnamed: C333.1, Q331.2, R333.2, U15.5
unnamed: C334.2, R334.1
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
